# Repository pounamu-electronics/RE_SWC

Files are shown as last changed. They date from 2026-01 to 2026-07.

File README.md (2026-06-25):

# RE_SWC - A volume knob kit for your car

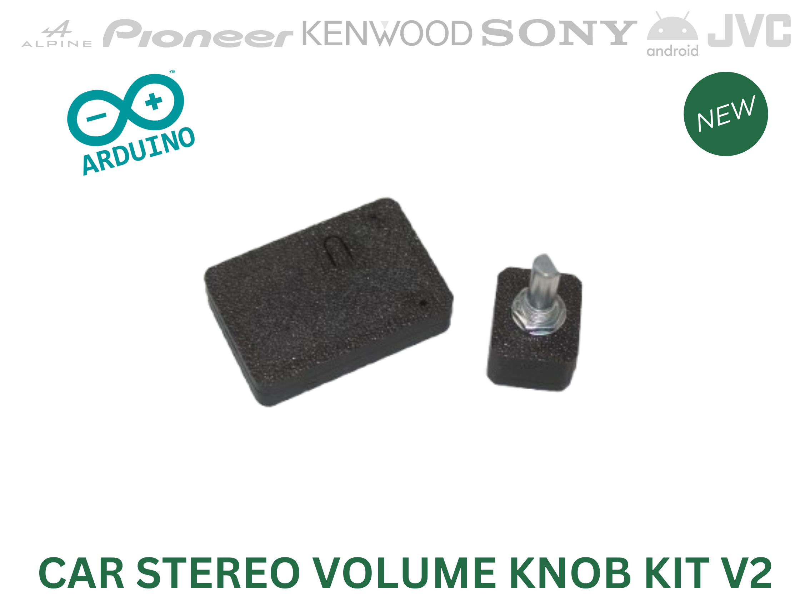
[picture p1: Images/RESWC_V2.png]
RE_SWC Product Render




### Features:

- Simple, **plug-and-play** solution. Mount the volume knob to a panel in the car, solder two wires into your stereo's steering wheel control input and you are good to go
- Compatible with many headunit brands and types
  - Generic Resistive (resistance learning supported by headunits)
  - JVC <sup>1</sup>
  - Kenwood <sup>2</sup>
  - Alpine
  - Pioneer
  - USB HID (single cable control for any android based units)
  - Sony
- **USB C powered**. Most headunits have female USB connectors for you to plug this into and power up
- MCU: WCH CH32X035 programnmed with the Arduino Framework
- Interrupt-driven firmware results in a smooth, **user-freindly** experience
- Firmware via USB upload - easy updates if required
- Fully **open source** hardware and firmware. This includes all design files, BOM, firmware, etc

<sup>1</sup> JVC forces incremental volume control above certain values on select models. I am yet to find a way to bypass this.

<sup>2</sup> Kenwood forces incremental volume control above certain values on select models. I have found a way to bypass this and have implemented it by default in the firmware. This may or may not work for your unit and your miles may vary.

### Default Output Mapping

| INPUT | OUTPUT |
| :---: | :---: |
| Volume Knob Clockwise Rotation (CW) | Volume+ |
| Volume Knob Counter Clockwise Rotation (CCW) | Volume- |
| Button Short Press | Mute/ATT |
| Button Long Press | Next Track |
| Button Double Press (Generic Resistive) | Enable Learning Mode |
| Button Double Press (Others) | Previous Track |

### Output Function Support

_FW v_4.0.0_

| OUTPUT | JVC | KENWOOD | ALPINE | PIONEER | USB HID | SONY |
| :---: | :---: | :---: | :---: | :---: | :---: | :---: |
| Volume+ | :heavy_check_mark: | :heavy_check_mark: | :heavy_check_mark: | :heavy_check_mark: | :heavy_check_mark: | :heavy_check_mark: |
| Volume- | :heavy_check_mark: | :heavy_check_mark: | :heavy_check_mark: | :heavy_check_mark: | :heavy_check_mark: | :heavy_check_mark: |
| Mute/ATT | :heavy_check_mark: | :heavy_check_mark: | :heavy_check_mark: | :heavy_check_mark: | :heavy_check_mark: | :heavy_check_mark: |
| Next Track | :heavy_check_mark: | :heavy_check_mark: | :heavy_check_mark: | :heavy_check_mark: | :heavy_check_mark: | :heavy_check_mark: |
| Previous Track | :heavy_check_mark: | :heavy_check_mark: | :heavy_check_mark: | :heavy_check_mark: | :heavy_check_mark: | :heavy_check_mark: |
| Play/Pause | :x: | :heavy_check_mark: | :x: | :x: | :heavy_check_mark: | :x: |
| Change Source  | :x: | :x: | :x: | :heavy_check_mark: | :x: | :x: |

### User Config

Remap all the input for the Volume Knob Kit to any supported output using the [Configurator Tool](https://pounamu-electronics.github.io/)

### User Guide

The User Guide can be found in the [Docs](Docs/) subfolder of this repository

### Firmware

The FW for this project is also completely open source and hosted [here on GitHub](https://github.com/lilindian16/RE_SWC_FW)

### Why did I make this?

- No kits like this exist: a plug-and-play solution to add a volume knob back into your car. Mount the volume knob to a panel in the car, solder two wires and you are good to go

### My headunit does not have a USB socket to power this??

No worries, purchase an automotive 12V to USB adapter and plug this into it.

- _Note: The 12V rail in cars is harsh. Do not cheap out on this component_

### FCC Compliance Statement

This device complies with Part 15 of the FCC Rules. Operation is subject to the following two conditions:

1.  This device may not cause harmful interference, and
2.  this device must accept any interference received, including interference that may cause undesired operation.

Please note, if you manufacture this yourself, FCC compliance is not valid. Pounamu Electronics is the sole manufacturer listed on the FCC SDoC.

### RESWC Impact Map

[RESWC Impact Map](https://www.google.com/maps/d/edit?mid=1JDZoqSFC2vp5jECxEuNOUrSM_snK-p8&usp=sharing)

### 3D Printed Housings - Design Files

You can find all design and production files for all housings (controller and encoder PCB) in this repo or head to thingiverse and download: [Thingiverse - RE_SWC Housings](https://www.thingiverse.com/thing:7272091)

### Volume Knob Dimensions

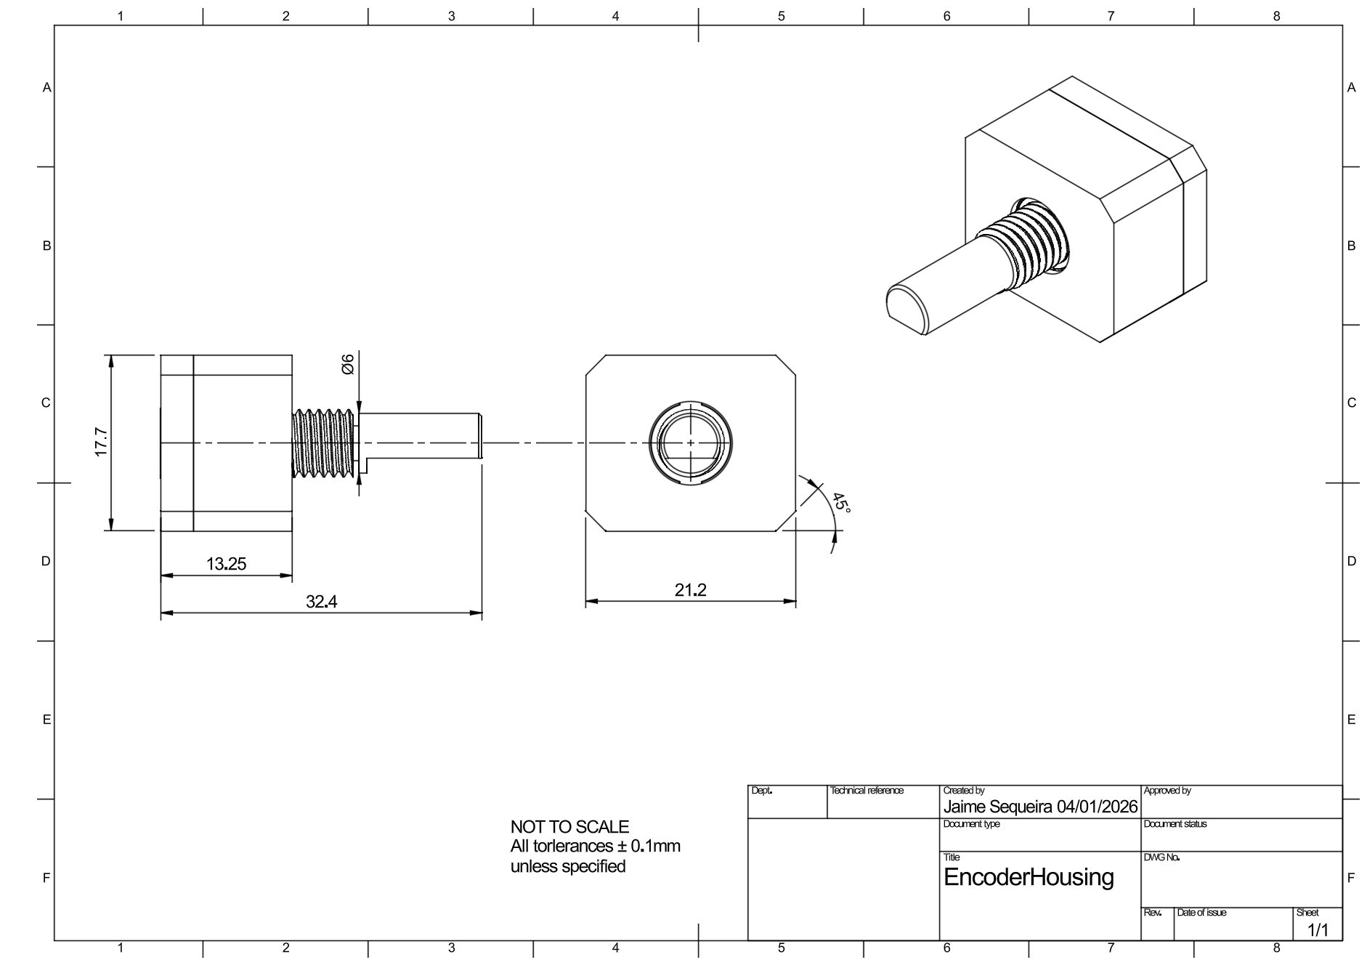
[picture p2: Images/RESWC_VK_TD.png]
Volume Knob Dimensions


### Controller Housing Dimensions

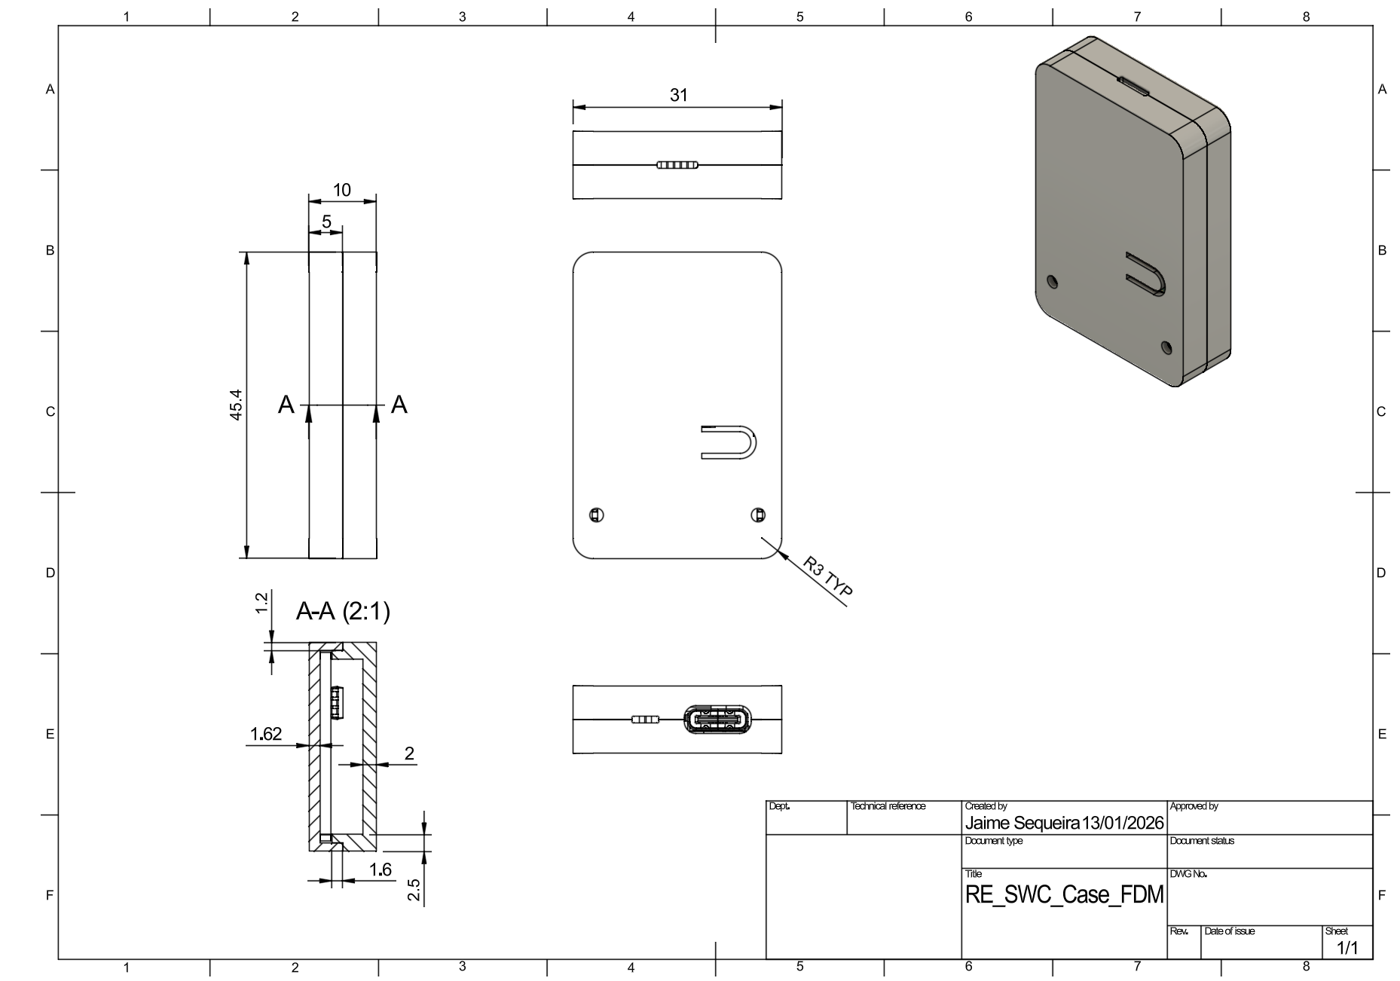
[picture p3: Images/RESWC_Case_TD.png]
Controller Housing Dimensions


### Board Bringup and O'Scope Captures

#### 3V3 Regulator

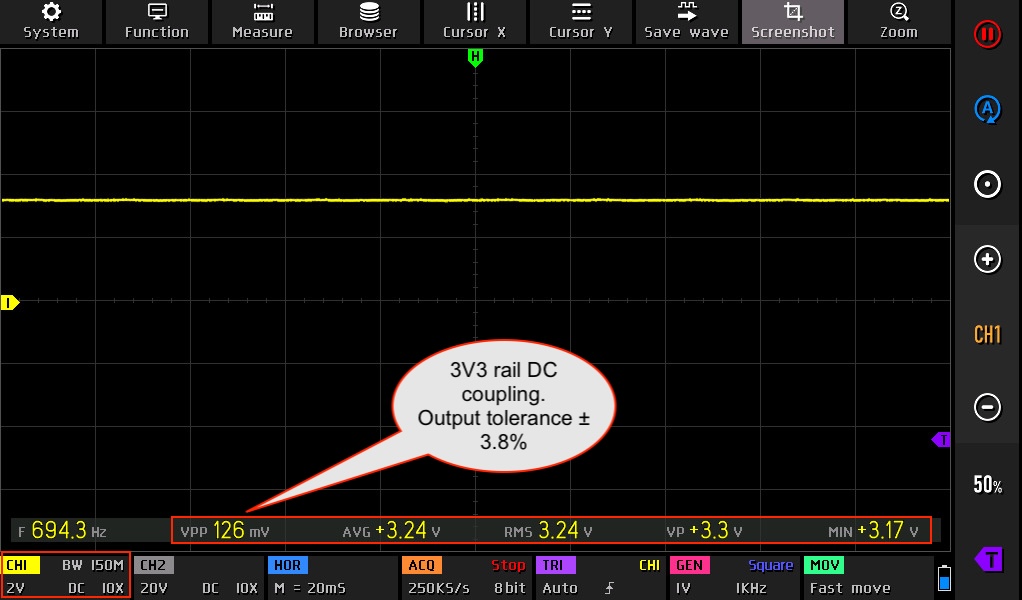
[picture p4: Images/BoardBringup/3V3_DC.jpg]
3V3 Regulator (HT7533-1) DC Coupling

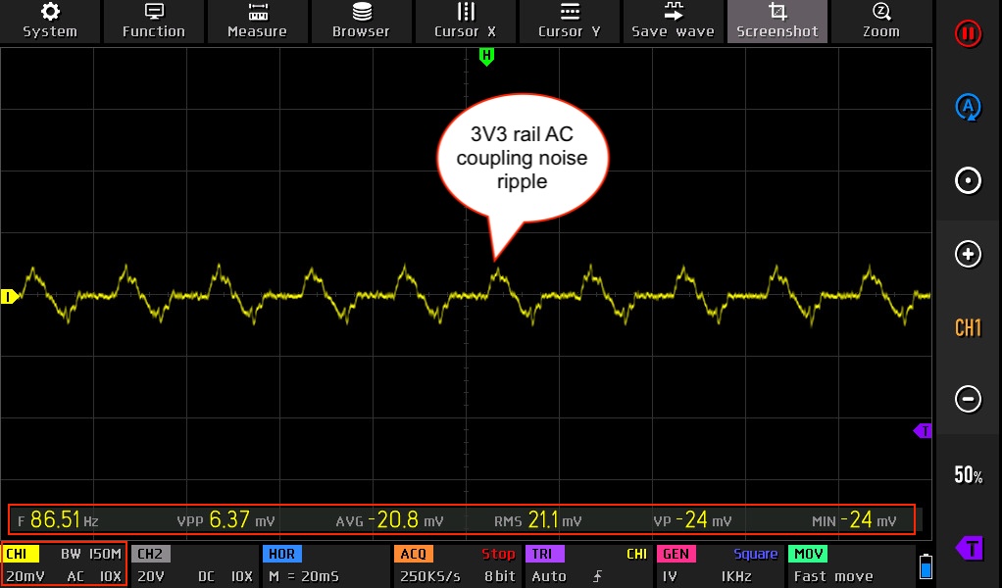
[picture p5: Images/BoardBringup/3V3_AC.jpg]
3V3 Regulator (HT7533-1) AC Coupling


#### Encoder CW, CCW Rotation and Button Press

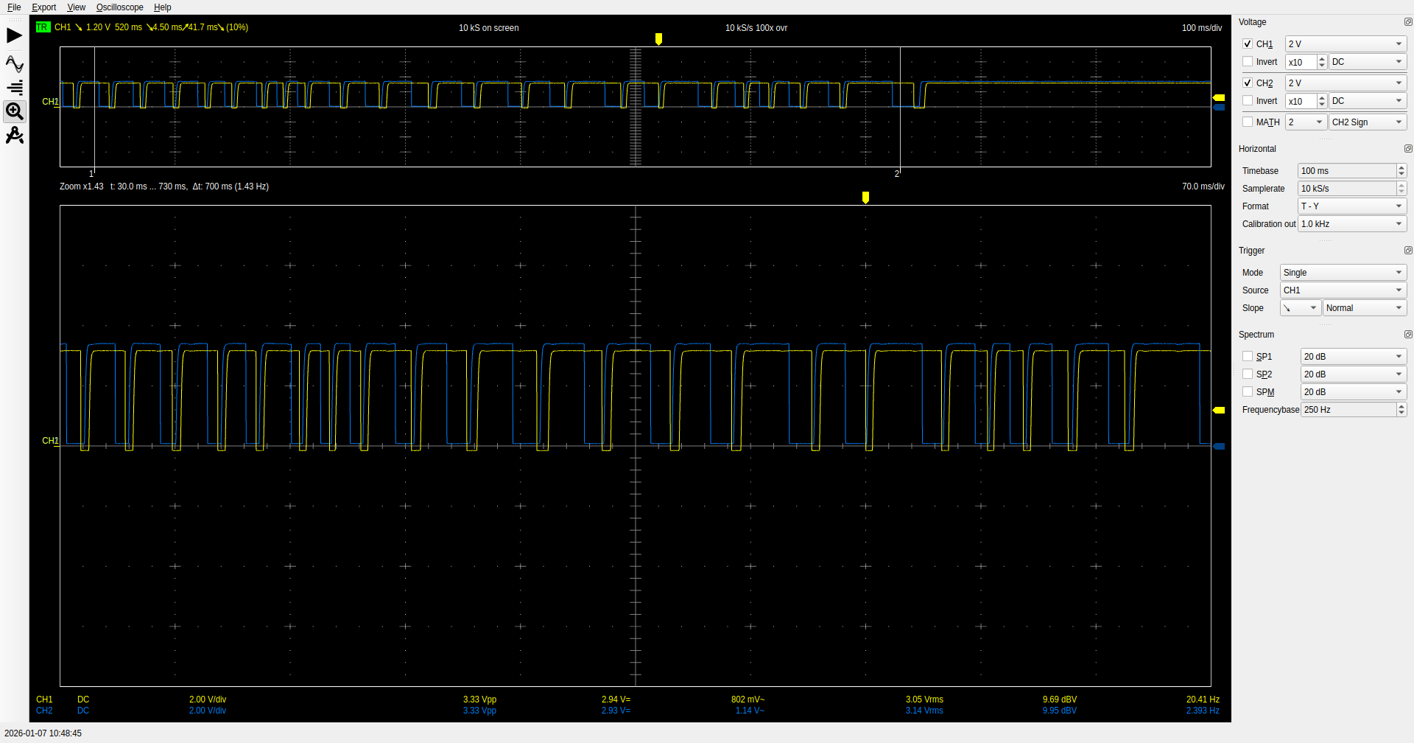
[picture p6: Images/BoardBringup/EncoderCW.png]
Encoder CW

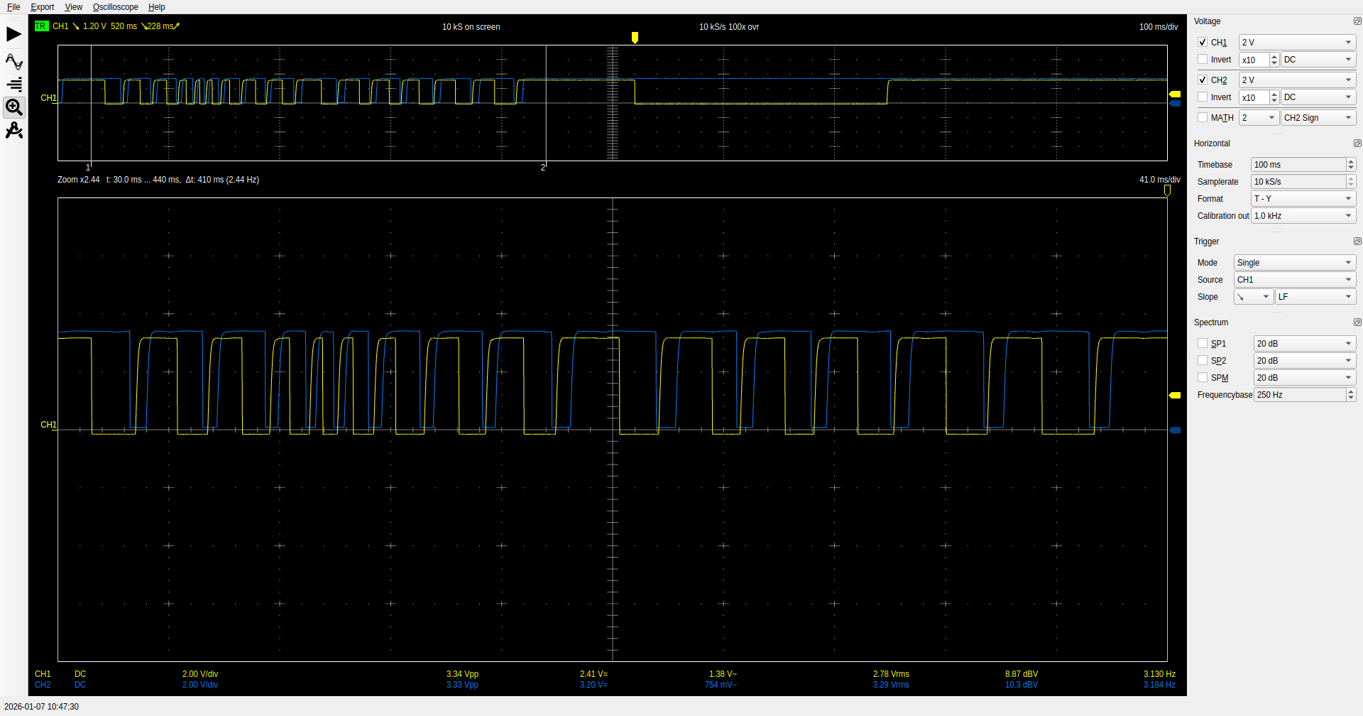
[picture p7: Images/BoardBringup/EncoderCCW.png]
Encoder CCW

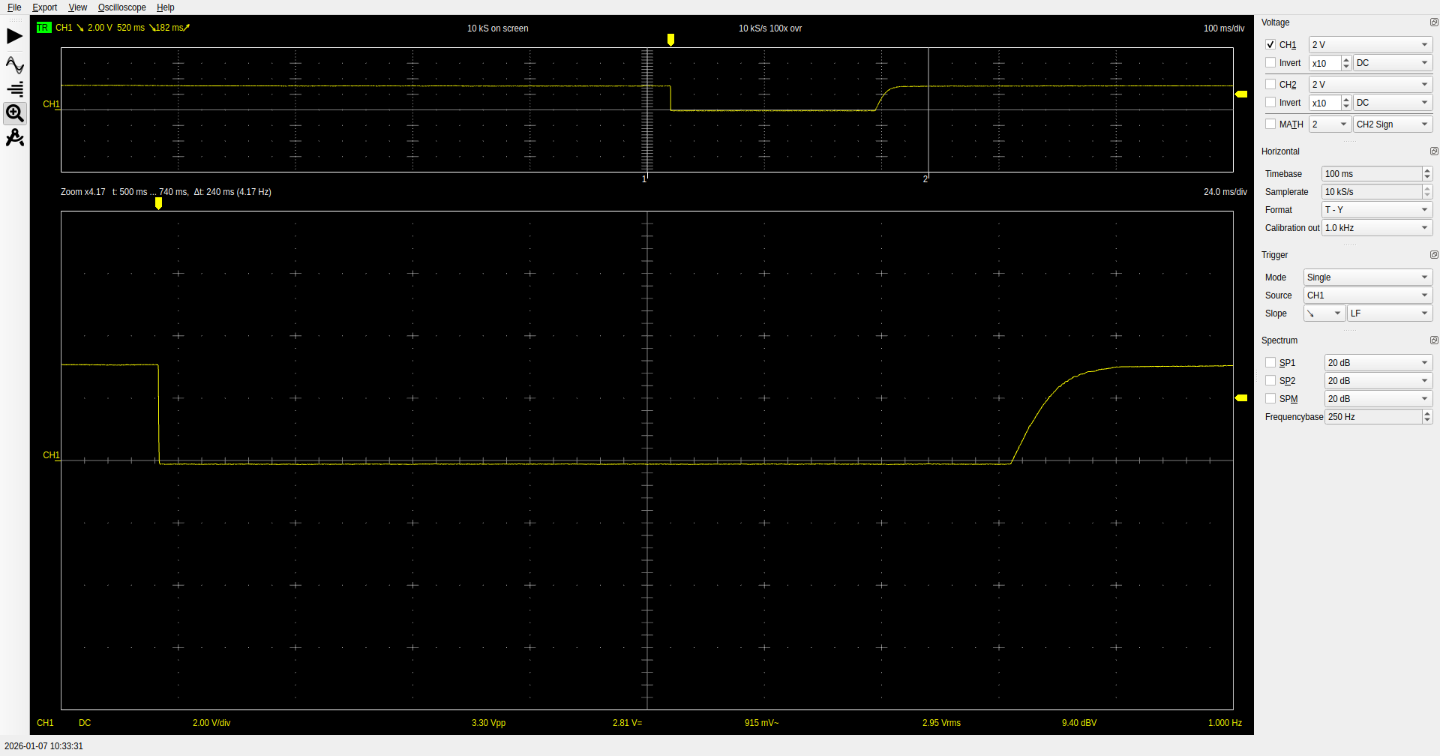
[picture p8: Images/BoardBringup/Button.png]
Encoder Button


#### SPI Bus (Mode 0)

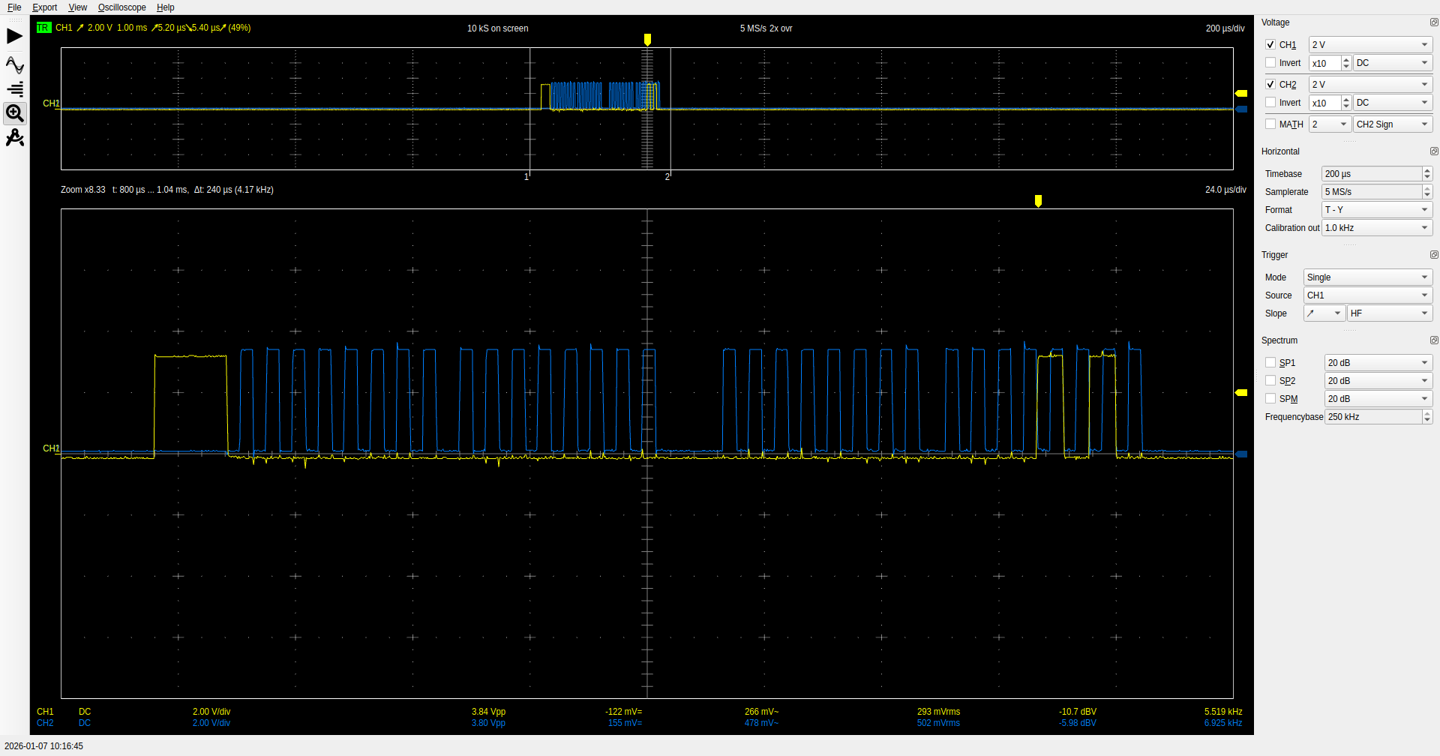
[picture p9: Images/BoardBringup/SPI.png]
SPI


#### Apline SWC Output

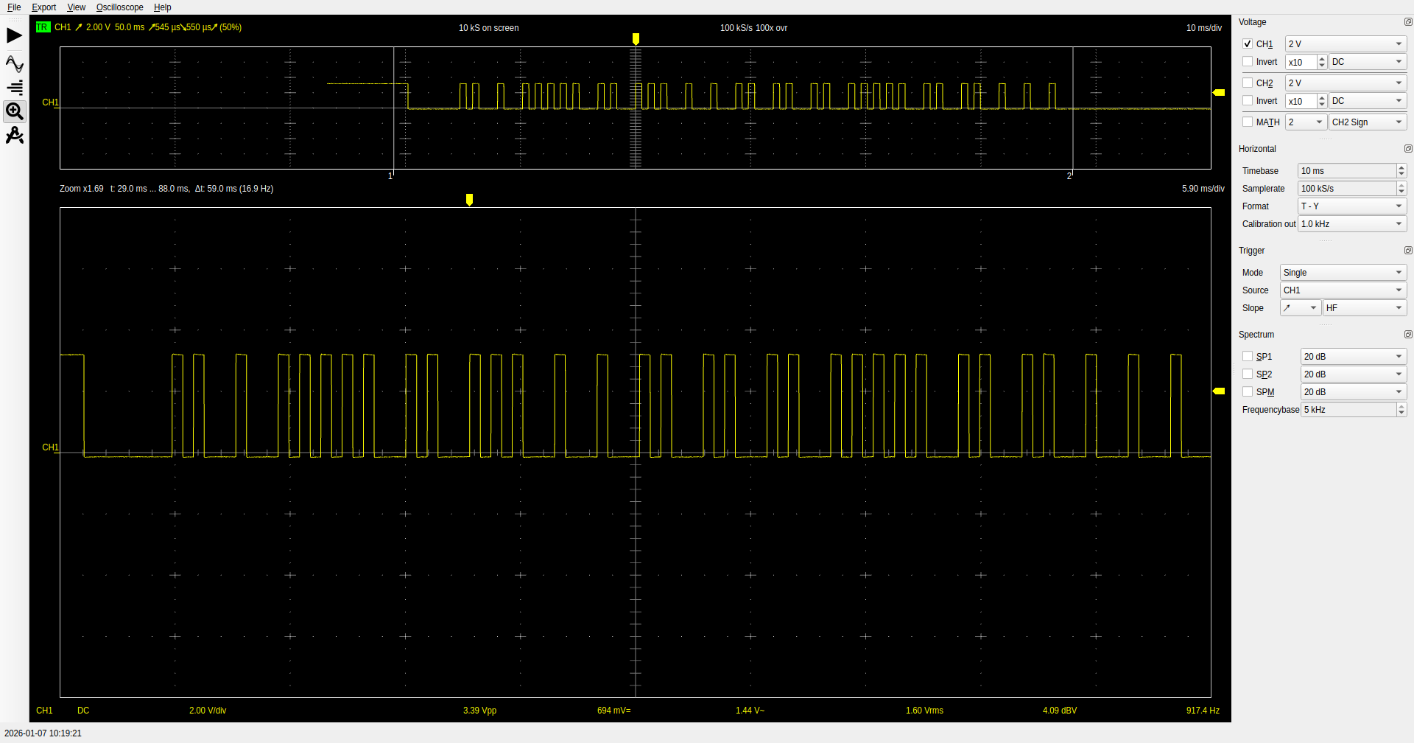
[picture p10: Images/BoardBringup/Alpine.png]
Alpine SWC Output


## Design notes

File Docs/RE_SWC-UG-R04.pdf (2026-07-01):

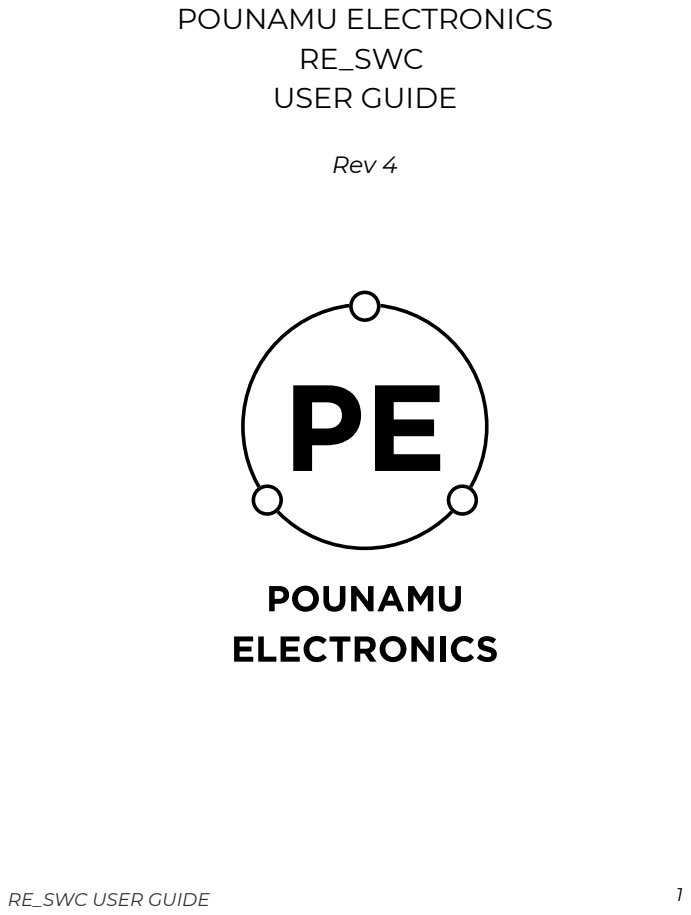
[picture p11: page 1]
RE_SWC USER GUIDE; POUNAMU ELECTRONICS RE_SWC USER GUIDE; Rev 4

3 | OVERVIEW
4 | INSTALLATION GUIDES
| 4 INSTALLATION - GENERIC RESISTIVE
| 5 INSTALLATION - JVC
| 6 INSTALLATION - KENWOOD
| 7 INSTALLATION - ALPINE
| 8 INSTALLATION - PIONEER
| 9 INSTALLATION - USB HID
| 10 INSTALLATION - SONY
11 | CONFIGURATION - HEADUNIT SELECTION
12 | HEADUNIT LEGEND
13 | DEFAULT FUNCTIONS
14 | ASSEMBLY TIPS
15 | VOLUME KNOB DIMESIONS
16 | TROUBLESHOOTING
17 | RE_SWC SPECS
18 | DISCLAIMERS
19 | COMPLIANCE
20 | DOCUMENT REVISION HISTORY

2

### Contents

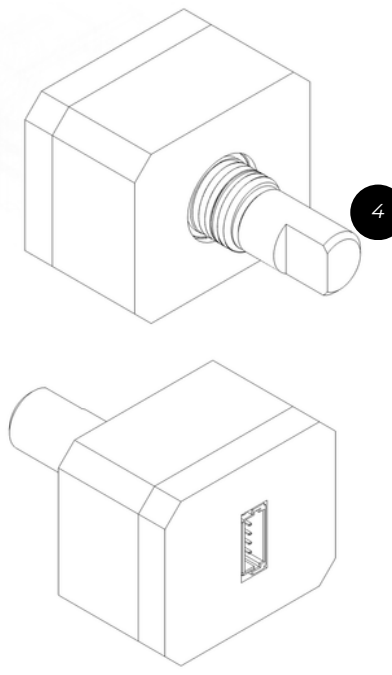
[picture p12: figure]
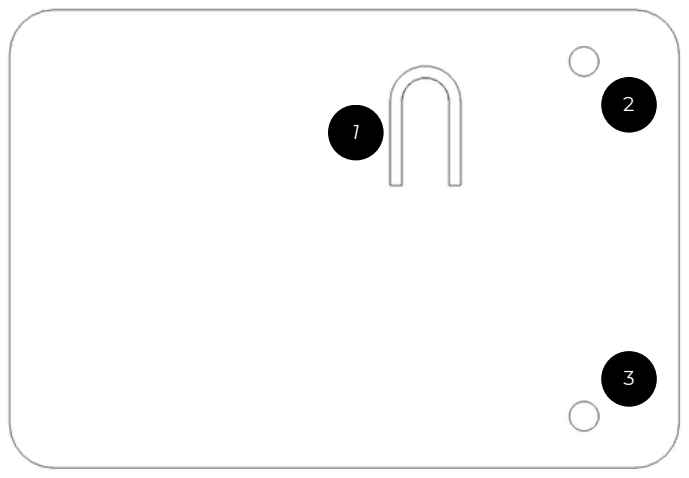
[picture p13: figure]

1. UPDATE BUTTON | 2. WHITE STATUS LIGHT
3. RED POWER LIGHT | 4. DIA 6mm ENCODER SHAFT
RE_SWC USER GUIDE | 3

### OVERVIEW

4

### INSTALLATION - GENERIC RESISTIVE

Solder the RED wire from the 2-pin connector on the RE_SWC kit to your headunit’s steering wheel control input pin (generally labelled KEY1 or KEY2)
If you purchased the 3.5mm patch cable, this will be the tip of the TRS jack
Solder the BLACK wire from the 2-pin connector into your harness if your headunit requires a reference for the SWC input (sometimes labelled ST REMOTE GND)
If you purchased the 3.5mm patch cable, this will be the sleeve of the TRS jack
Power the kit with a USB C cable.
NOTE: This kit requires 5V USB power only The RED power indicator on the RE_SWC will illuminate and stay on

5

### INSTALLATION - JVC

Solder the RED wire from the 2-pin connector on the RE_SWC kit to your headunit’s steering wheel control input pin (normally a blue and yellow wire)
If you purchased the 3.5mm patch cable, this will be the tip of the TRS jack
Power the kit with a USB C cable.
NOTE: This kit requires 5V USB power only The RED power indicator on the RE_SWC will illuminate and stay on
The RE_SWC kit will operate without any further configuration on your headunit

6

### INSTALLATION - KENWOOD

Solder the RED wire from the 2-pin connector on the RE_SWC kit to your headunit’s steering wheel control input pin (normally a blue and yellow wire)
If you purchased the 3.5mm patch cable, this will be the tip of the TRS jack
Power the kit with a USB C cable.
NOTE: This kit requires 5V USB power only The RED power indicator on the RE_SWC will illuminate and stay on
The RE_SWC kit will operate without any further configuration on your headunit

7

### INSTALLATION - ALPINE

Plug the RE_SWC into your unit using the 3.5mm patch cable
You can make a compatible 3.5mm patch cable yourself by soldering the red wire from the 2-pin connector on the RE_SWC kit to the tip of the 3.5mm jack. Leave the ring and sleeve floating
Power the kit with a USB C cable.
NOTE: This kit requires 5V USB power only The RED power indicator on the RE_SWC will illuminate and stay on
The RE_SWC kit will operate without any further configuration on your headunit

8

### INSTALLATION - PIONEER

Plug the RE_SWC into your unit using the 3.5mm patch cable
You can make a compatible 3.5mm patch cable yourself by soldering the red wire from the 2-pin connector on the RE_SWC kit to the tip of the 3.5mm jack. Leave the ring and sleeve floating
Power the kit with a USB C cable.
NOTE: This kit requires 5V USB power only The RED power indicator on the RE_SWC will illuminate and stay on
Ensure “With Adapter” is set in the Steering Wheel Controls menu on your headunit
The RE_SWC kit will operate without any further configuration on your headunit

9

### INSTALLATION - USB HID

Connect the RE_SWC kit to your device with a USB C cable (must support data & 5V power) Note: Do not use this device with any power source higher than standard USB 5V
The RED power indicator on the RE_SWC will illuminate and stay on

10

### INSTALLATION - SONY

Plug the RE_SWC into your unit using the 3.5mm patch cable
You can make a compatible 3.5mm patch cable yourself by soldering the red wire from the RE_SWC kit to the tip of the 3.5mm jack. Leave the ring and sleeve floating
Power the kit with a USB C cable.
NOTE: This kit requires 5V USB power only The RED power indicator on the RE_SWC will illuminate and stay on
In the Steering Wheel Controls menu, set the [Custom] switch to [OFF]
On some units, you may need to set it to be “With Adapter”
The RE_SWC kit will operate without any further configuration on your headunit

11

### CONFIGURATION - HEADUNIT SELECTION

Ensure RE_SWC is not powered
Press and hold the volume knob. Connect power to the RE_SWC while keeping the volume knob held
Release the volume knob after the WHITE status light is illuminated
Press the volume knob once. The WHITE status light will flash once. Headunit number 1 is now programmed. Repeat this step until the desired headunit number is reached - refer to the headunit legend
When the desired headunit number is entered, press and hold the volume knob. The WHITE status light will flash. Release the volume knob. The RE_SWC will flash x times where x is the headunit number entered

12

### HEADUNIT LEGEND

HEADUNIT NUMBER | HEADUNIT TYPE / BRAND

1 GENERIC RESISTIVE

2 JVC

3 KENWOOD

4 ALPINE

5 PIONEER

6 USB HID

7 SONY

13

### DEFAULT FUNCTIONS

INPUT | OUTPUT
Volume Knob CW | Volume +
Volume Knob CCW | Volume -
Button Short Press | Mute
Button Long Press | Next Track
Button Double Press (Generic Resistive mode) | Enable Learning Mode
Button Double Press (Other Modes) | Previous Track

RE_SWC USER GUIDE | 14

### ASSEMBLY TIPS

Mounting the knob
Drill a pilot hole between 1 and 3mm in diameter Widen the hole to 7.5mm
Mount the knob into the hole and secure with the included washer and nut

Powering the RE

_

SWC
The RE_SWC uses 5V USB power. Do not use any higher voltage
The RE_SWC boots up almost instantaneously. You can power the device with a switched 5V USB power supply. Configuration settings are retained between power cycles

Note
The RE_SWC will be shipped pre-configured in the mode selected during the checkout process for a plug-and-play setup

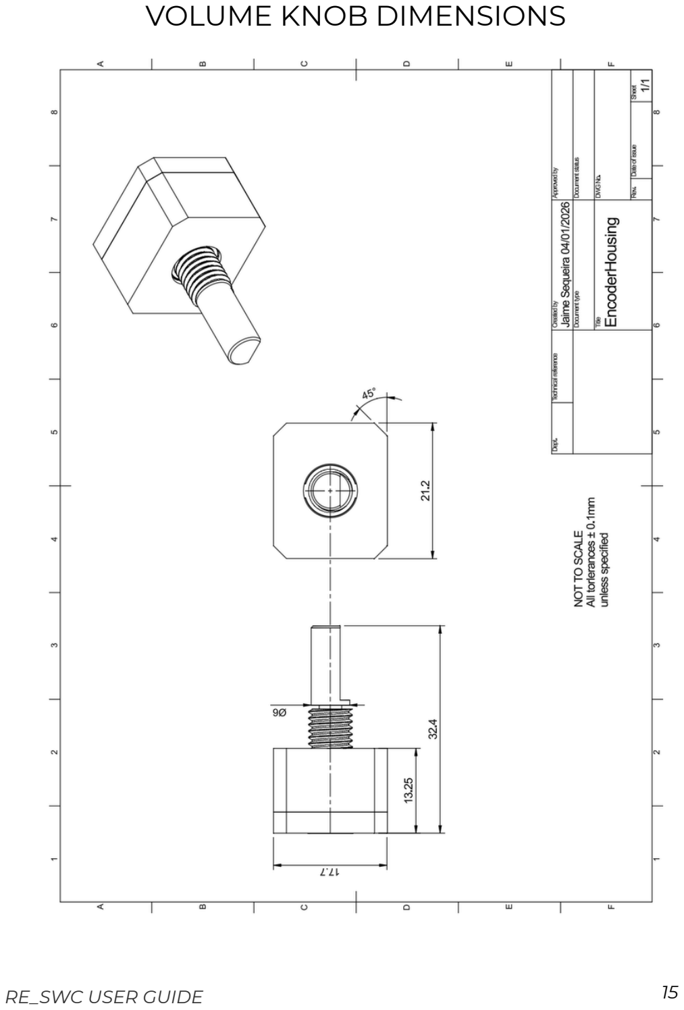
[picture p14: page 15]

RE_SWC USER GUIDE | 15

### VOLUME KNOB DIMENSIONS

16

### TROUBLESHOOTING

The RED power light is off
Ensure you are powering the kit with 5V USB power

The RED power light is on but the WHITE status light does not flash when I use the knob Ensure the 5-pin connector harness for the knob is seated correctly and inserted fully into the knob and the kit

The WHITE status light flashes when I turn the knob but my headunit does nothing
Ensure you have set the kit in the correct headunit mode
Ensure the RED wire from the 2-pin connector is soldered properly into your headunit’s harness

My headunit shows the volume increasing but the volume of my music doesn’t change in USB HID mode
Some Android headunits do not route USB volume commands to the correct hardware. Revert to using the Resistive SWC mode with Key1 / Key 2 input wire instead

### RE_SWC SPECS

Input
Power: 5V / 100mA USB-C
SWC Header: 5V max. Do not connect to 12V signal

CONNECTORS
VOLUME KNOB: JST SHR-05V-S-B SWC OUT: JST SHR-02V-S-B

MCU:
WCH CH32X035F8U6

Digital Rheostat:
MCP4131-104E/SN
SPI @ 250kHz
RE_SWC USER GUIDE | 17

18

### DISCLAIMERS

Pounamu Electronics is not affiliated or associated with any headunit manufacturers or brands
Pounamu Electronics is not affiliated or associated with the USB Implementers Forum (USB-IF)

19

### COMPLIANCE

FCC Compliance Statement
This device complies with Part 15 of the FCC Rules. Operation is subject to the following two
conditions:
1. This device may not cause harmful interference, and
2. this device must accept any interference received, including interference that may cause undesired operation.

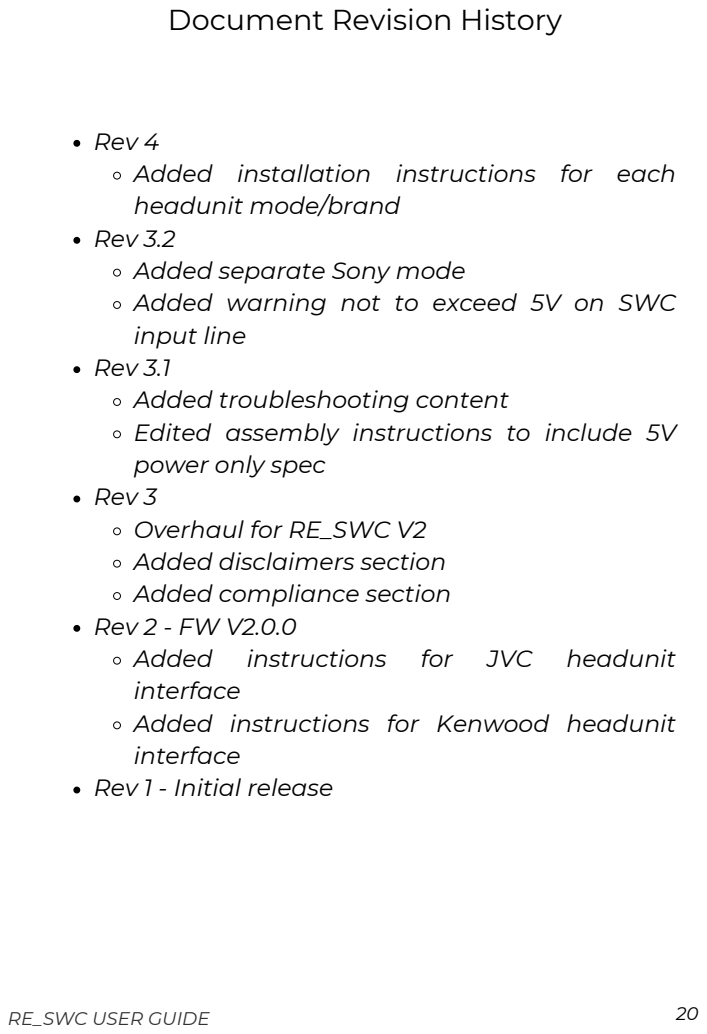
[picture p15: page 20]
RE_SWC USER GUIDE

Document Revision History

Rev 4
Added installation instructions for each
headunit mode/brand
Rev 3.2
Added separate Sony mode
Added warning not to exceed 5V on SWC
input line
Rev 3.1
Added troubleshooting content
Edited assembly instructions to include 5V
power only spec
Rev 3
Overhaul for RE_SWC V2
Added disclaimers section
Added compliance section
Rev 2 - FW V2.0.0
Added instructions for JVC headunit
interface
Added instructions for Kenwood headunit
Rev 1 - Initial release

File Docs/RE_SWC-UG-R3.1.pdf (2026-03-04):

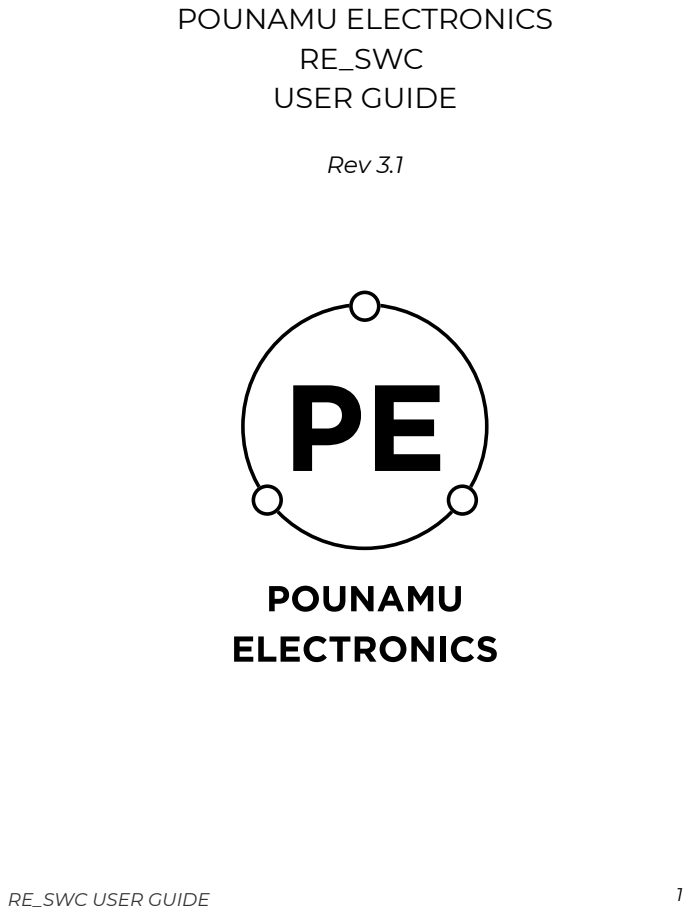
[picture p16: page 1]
RE_SWC USER GUIDE; POUNAMU ELECTRONICS RE_SWC USER GUIDE; Rev 3.1

3 | OVERVIEW
4 | ASSEMBLY
5 | CONFIGURATION - HEADUNIT SELECTION
6 | HEADUNIT LEGEND
7 | FUNCTIONS
8 | VOLUME KNOB DIMESIONS
9 | TROUBLESHOOTING
10 | RE_SWC SPECS
11 | DISCLAIMERS
12 | COMPLIANCE
13 | DOCUMENT REVISION HISTORY

2

### Contents


1. UPDATE BUTTON | 2. WHITE STATUS LIGHT
3. RED POWER LIGHT | 4. DIA 6mm ENCODER SHAFT
RE_SWC USER GUIDE | 3

### OVERVIEW

RE_SWC USER GUIDE | 4

### ASSEMBLY

Solder the RED wire from the 2-pin connector on the RE_SWC kit to your headunit’s steering wheel control input pin
Solder the BLACK wire from the 2-pin connector into your harness if your headunit requires a reference for the SWC input (sometimes labelled ST REMOTE GND)
Power the kit with a USB C cable.
NOTE: This kit requires 5V USB power only The RED power indicator on the RE_SWC will imlluminate and stay on

USB HID
Connect the RE_SWC kit to your device with a USB C cable (must support data & 5V power) The RED power indicator on the RE_SWC will imlluminate and stay on

Others

5

### CONFIGURATION

HEADUNIT SELECTION

Ensure RE_SWC is not powered
Press and hold the volume knob. Connect power to the RE_SWC while keeping the volume knob held
Release the volume knob after the WHITE status light is illuminated
Press the volume knob once. The WHITE status light will flash once. Headunit number 1 is now programmed. Repeat this step until the desired headunit number is reached - refer to the headunit legend
When the desired headunit number is entered, press and hold the volume knob. The WHITE status light will flash. Release the volume knob. The RE_SWC will flash x times where x is the headunit number entered

6

### HEADUNIT LEGEND

HEADUNIT NUMBER | HEADUNIT TYPE / BRAND

1 GENERIC RESISTIVE

2 JVC

3 KENWOOD

4 ALPINE

5 PIONEER / SONY

6 USB HID

7

### FUNCTIONS

INPUT | GENERIC RESISTIVE | JVC | KENWOOD | ALPINE | PIONEER / SONY | USB HID
Volume Knob CW | Any | Volume + | Volume + | Volume + | Volume + | Volume +
Volume Knob CCW | Any | Volume - | Volume - | Volume - | Volume - | Volume -
Button Short Press | Any | Mute | Mute | Mute | Mute | Mute
Button Long Press | Any | Next Track | Next Track | Next Track | Next Track | Next Track
Button Double Press | Enter Learning Mode | Previous Track | Previous Track | Previous Track | Previous Track | Previous Track

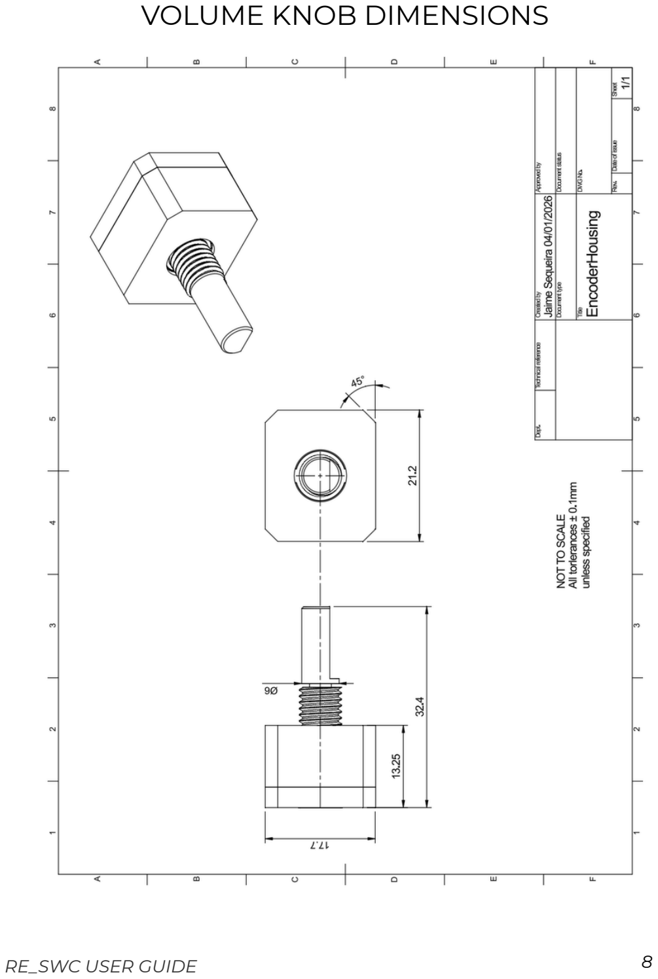
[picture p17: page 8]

RE_SWC USER GUIDE | 8

### VOLUME KNOB DIMENSIONS

9

### TROUBLESHOOTING

The RED power light is off
Ensure you are powering the kit with 5V USB power

The RED power light is on but the WHITE status light does not flash when I use the knob Ensure the 5-pin connector harness for the knob is seated correctly and inserted fully into the knob and the kit

The WHITE status light flashes when I turn the knob but my headunit does nothing
Ensure you have set the kit in the correct headunit mode
Ensure the RED wire from the 2-pin connector is soldered properly into your headunit’s harness

My headunit shows the volume increasing but the volume of my music doesn’t change in USB HID mode
Some Android headunits do not route USB volume commands to the correct hardware. Revert to using the Resistive SWC mode with Key1 / Key 2 input wire instead

### RE_SWC SPECS

Input
5V / 100mA USB-C

CONNECTORS
VOLUME KNOB: JST SHR-05V-S-B SWC OUT: JST SHR-02V-S-B

MCU:
WCH CH32X035F8U6

Digital Rheostat:
MCP4131-104E/SN
SPI @ 250kHz
RE_SWC USER GUIDE | 10

11

### DISCLAIMERS

Pounamu Electronics is not affiliated or associated with any headunit manufacturers or brands
Pounamu Electronics is not affiliated or associated with the USB Implementers Forum (USB-IF)

12

### COMPLIANCE

FCC Compliance Statement
This device complies with Part 15 of the FCC Rules. Operation is subject to the following two
conditions:
1. This device may not cause harmful interference, and
2. this device must accept any interference received, including interference that may cause undesired operation.

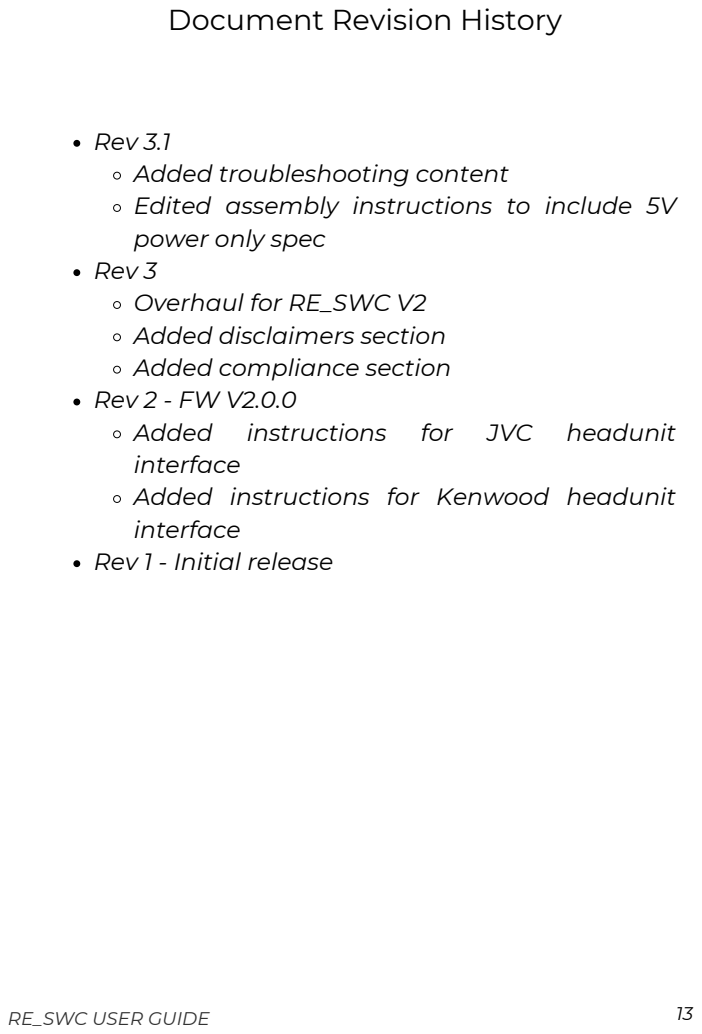
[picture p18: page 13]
RE_SWC USER GUIDE

Document Revision History

Rev 3.1
Added troubleshooting content
Edited assembly instructions to include 5V
power only spec
Rev 3
Overhaul for RE_SWC V2
Added disclaimers section
Added compliance section
Rev 2 - FW V2.0.0
Added instructions for JVC headunit
interface
Added instructions for Kenwood headunit
Rev 1 - Initial release

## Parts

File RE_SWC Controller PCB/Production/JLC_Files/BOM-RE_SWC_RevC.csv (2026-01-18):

Comment | Designator | Footprint | LCSC | Quantity
SM05B-SRSS-TB | J104 | JST_SH_SM05B-SRSS-TB_1x05-1MP_P1.00mm_Horizontal | C136657 | 1
HT7533-1 | U102 | SOT-89-3 | C14289 | 1
100n | C101,C102,C107,C109,C111 | C_0603_1608Metric | C14663 | 5
SM02B-SRSS-TB | J106 | JST_SH_SM02B-SRSS-TB_1x02-1MP_P1.00mm_Horizontal | C160402 | 1
1N5819WS | D109 | D_SOD-323_HandSoldering | C191023 | 1
H3V3SD3B | D102,D105,D106 | D_SOD-323_HandSoldering | C20615802 | 3
H5VSD3B | D107 | D_SOD-323_HandSoldering | C20615806 | 1
AO3400A | Q104 | SOT-23 | C20917 | 1
LED_RED | D103 | LED_0603_1608Metric_Pad1.05x0.95mm_HandSolder | C2286 | 1
LED_WHITE | D104 | LED_0603_1608Metric_Pad1.05x0.95mm_HandSolder | C2290 | 1
330R | R101,R103,R104,R105,R112,R118,R126,R129 | R_0603_1608Metric | C23138 | 8
4R7 | R123 | R_0603_1608Metric | C23164 | 1
5k1 | R119,R120,R127,R128 | R_0603_1608Metric | C23186 | 4
BOOT | SW101 | SW_SPST_B3U-1000P-B | C256107 | 1
GT-USB-7010ASV | J101 | USB_C_Receptacle_G-Switch_GT-USB-7010ASV | C2988369 | 1
CH32X035F8U6 | U107 | QFN-20-1EP_3x3mm_P0.4mm_EP1.65x1.65mm | C42442062 | 1
10n | C105,C106 | C_0603_1608Metric | C57112 | 2
MCP4131-104E/SN | U105 | SOIC-8_3.9x4.9mm_P1.27mm | C636034 | 1
USBLC6-2SC6 | U106 | SOT-23-6 | C7519 | 1
10u | C103,C104,C112 | C_0603_1608Metric | C96446 | 3

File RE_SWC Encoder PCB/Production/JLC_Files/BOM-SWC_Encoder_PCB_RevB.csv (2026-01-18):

Comment | Designator | Footprint | LCSC | Quantity
Rotary Encoder | SW101 | RotaryEncoder_Bourns_Vertical_PEC12R-3x17F-Sxxxx | C19712528 | 1
BM05B-SRSS-TBT(LF)(SN) | J101 | JST_SH_BM05B-SRSS-TB_1x05-1MP_P1.00mm_Vertical | C265092 | 1

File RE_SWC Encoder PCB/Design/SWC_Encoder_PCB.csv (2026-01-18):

Reference | Qty | DNP | Manufacturer | MPN | LCSC | Value | Footprint | Datasheet
SW101 | 1 |  | CTR | ED11305M-FB18.5A10-E20-160-G219 | C19712528 | Rotary Encoder | Rotary_Encoder:RotaryEncoder_Bourns_Vertical_PEC12R-3x17F-Sxxxx | https://lcsc.com/datasheet/lcsc_datasheet_2410121342_CTR-ED11305M-FB18-5A10-E20-160-G219_C19712528.pdf
J101 | 1 |  | JST | BM05B-SRSS-TBT(LF)(SN) | C265092 | BM05B-SRSS-TBT(LF)(SN) | Connector_JST:JST_SH_BM05B-SRSS-TB_1x05-1MP_P1.00mm_Vertical | https://www.lcsc.com/datasheet/lcsc_datasheet_2004071004_JST-BM05B-SRSS-TBT-LF-SN_C265092.pdf

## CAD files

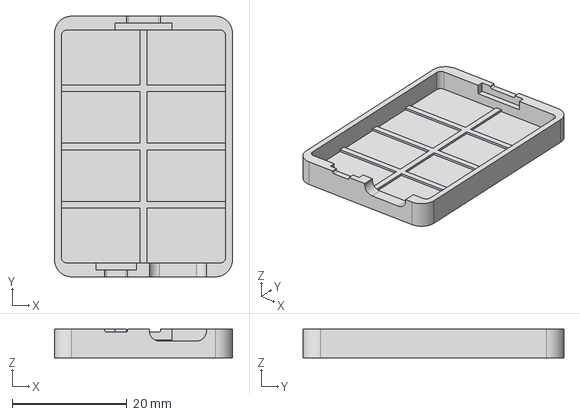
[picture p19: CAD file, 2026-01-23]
RE_SWC Controller Case/FDM/STEP/CaseBase.step
31.0 x 45.4 x 5.00 mm

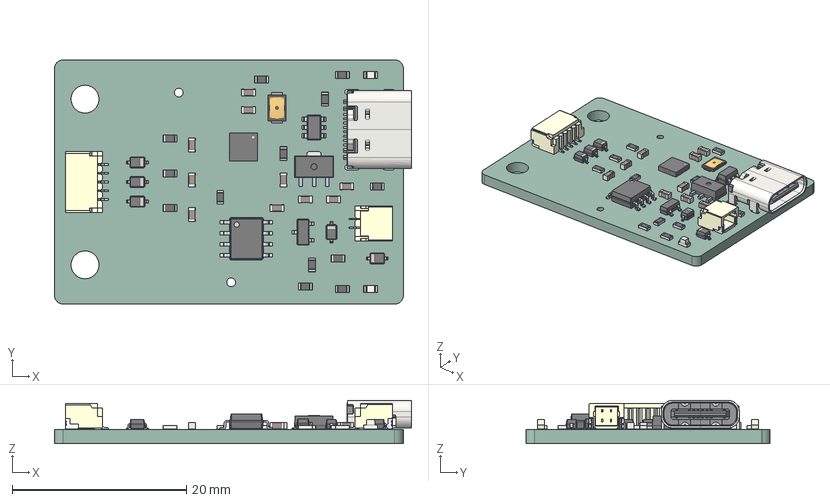
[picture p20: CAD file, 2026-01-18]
RE_SWC Controller PCB/Design/RE_SWC_Controller_PCB.step
40.9 x 28.0 x 4.96 mm
R_0603_1608Metric x 13
C_0603_1608Metric x 10
QFN-20-1EP_4x4mm_Pitch0.5mm
D_SOD_323 x 5
3x2x0.65mm
CQ assembly
SM02B-SRSS-TB(LF)(SN)
SOT_23
SOT_23_6
USB_C_Receptacle_16P_TopMnt_Horizontal_GCT_USB4105-xx-A
LED_0603_1608Metric x 2
SOIC_8_39x49mm_P127mm
SM05B-SRSS-TB-LFS
RE_SWC_RevC_PCB

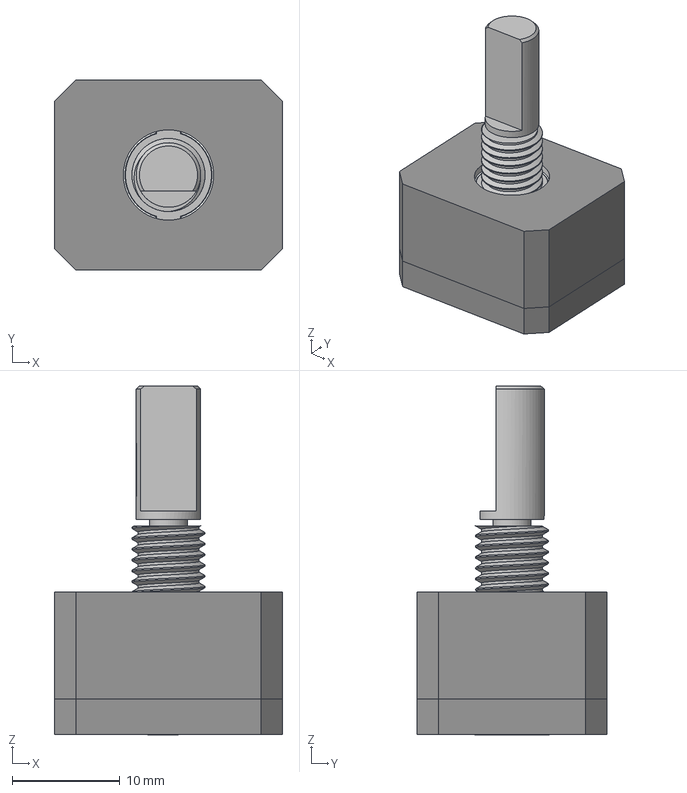
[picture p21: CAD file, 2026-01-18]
RE_SWC Encoder Case/STEP/Encoder_Housing_bottom.step
21.2 x 17.7 x 32.4 mm
EC11_20mm v1
BM05B-SRSS-TB(LF)(SN)
SWC_Encoder_PCB_RevB_PCB

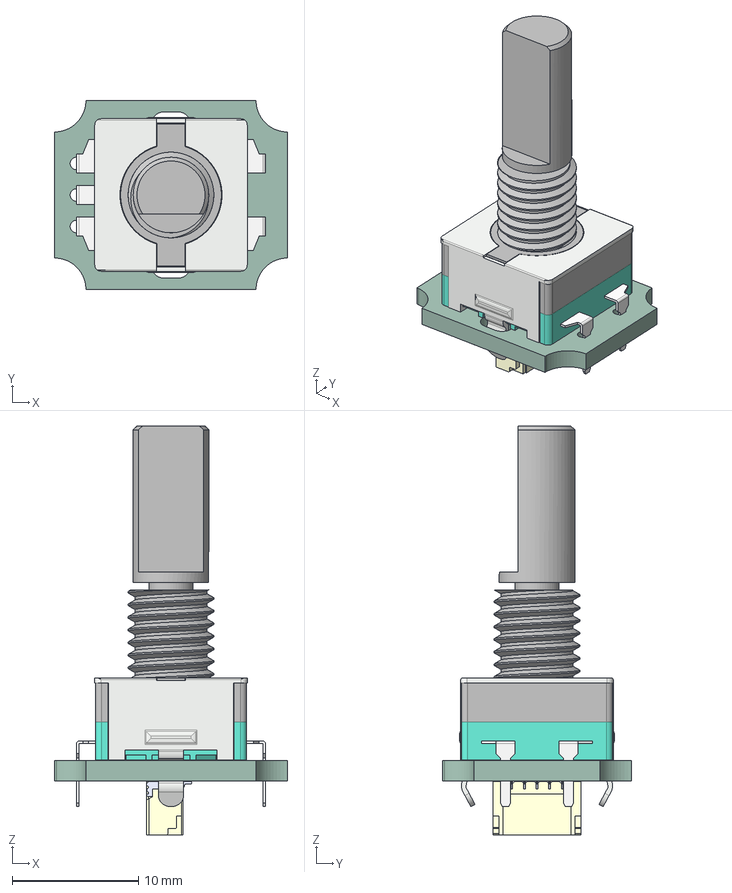
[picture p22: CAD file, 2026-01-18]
RE_SWC Encoder PCB/Design/SWC_Encoder_PCB_RevB.step
18.5 x 15.0 x 32.4 mm
EC11_20mm v1
BM05B-SRSS-TB(LF)(SN)
SWC_Encoder_PCB_RevB_PCB

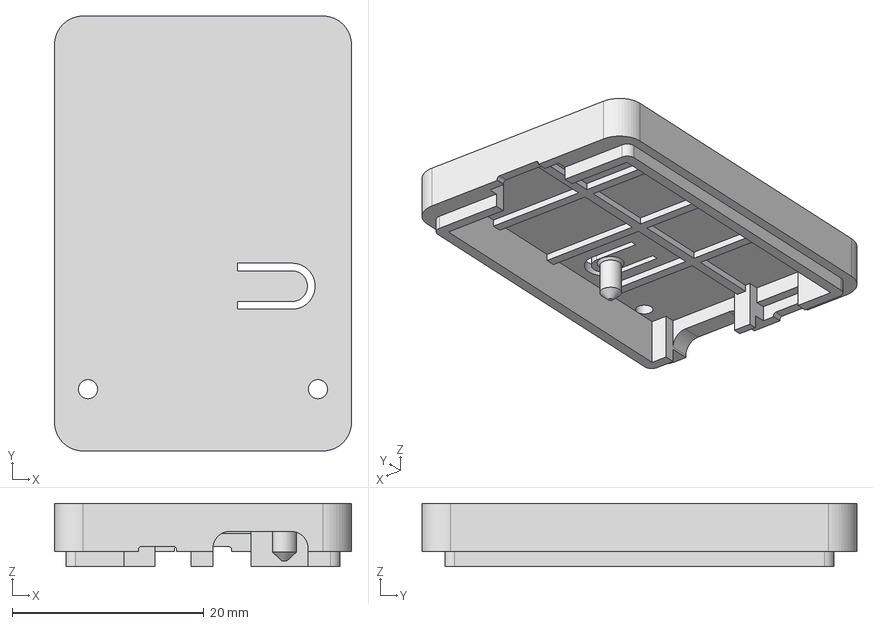
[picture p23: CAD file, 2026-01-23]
RE_SWC Controller Case/FDM/STEP/CaseLid.step
31.0 x 45.4 x 6.60 mm

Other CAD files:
RE_SWC Encoder Case/STEP/Encoder_Housing_top.step
RE_SWC Controller Case/FDM/STL/CaseBase.stl
RE_SWC Controller Case/FDM/STL/CaseLid.stl
RE_SWC Encoder Case/STL/Encoder_Housing_bottom.stl
RE_SWC Encoder Case/STL/Encoder_Housing_top.stl

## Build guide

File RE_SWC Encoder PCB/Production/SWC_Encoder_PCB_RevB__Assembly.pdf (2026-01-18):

No | Not specified | 0.01 | mm

# Min hole diameter: Not specified

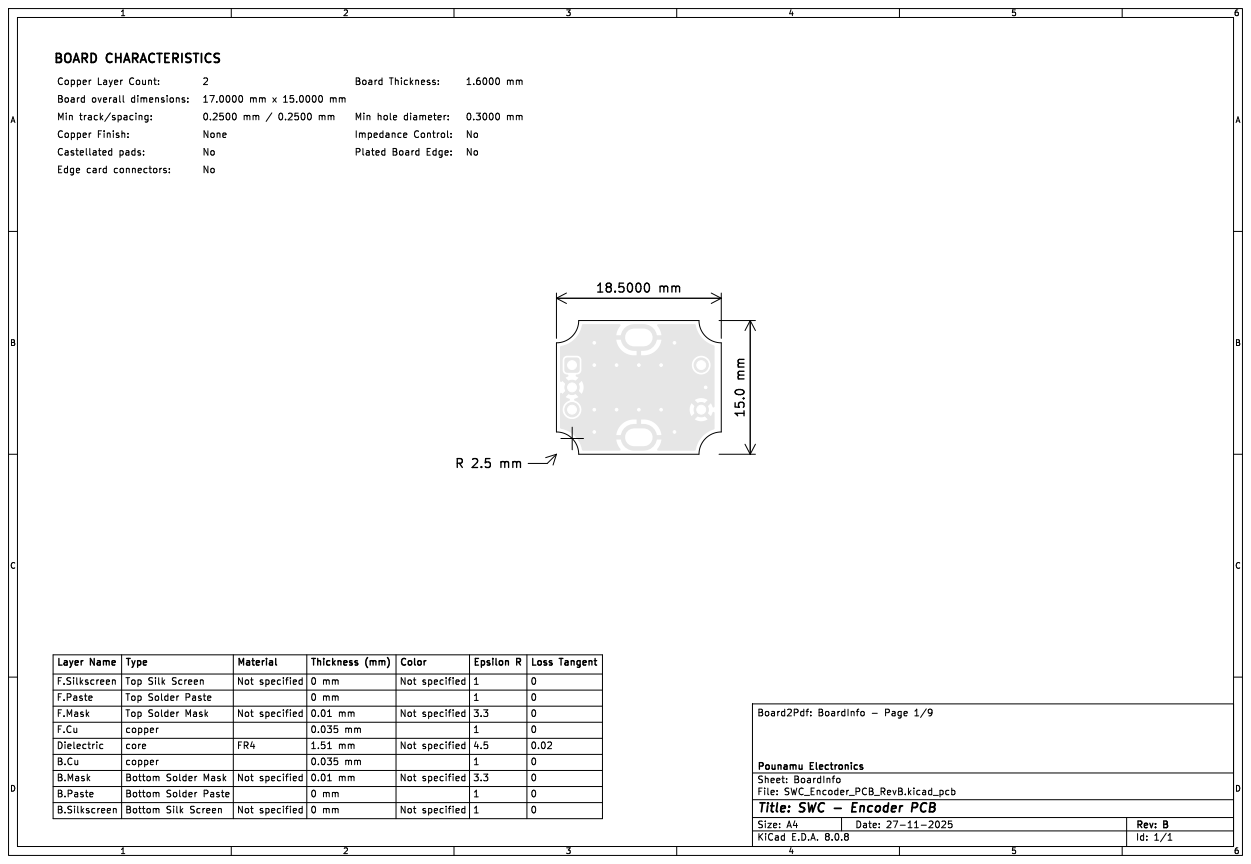
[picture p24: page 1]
D Date: 27-11-2025 KiCad; E.D.A. 8.0.8 Size: A4; Rev:; File: SWC_Encoder_PCB_RevB.kicad_pcb Sheet: BoardInfo Pounamu; Electronics Board2Pdf:; BoardInfo; Page; Board; Thickness:; Impedance; Control:; B.Paste; Edge card; connectors:; Not specified; B.Mask; Epsilon; Board overall; dimensions:; Castellated; pads:; BOARD CHARACTERISTICS; Copper Finish:; None

Copper Layer Count:
Min track/spacing:

Plated Board Edge:

Top Solder Paste | | 0 mm | | | 0 F.Mask Dielectric Layer Name F.Paste F.Cu

Bottom Solder Mask F.Silkscreen | | Screen Top Solder | Screen Mask | | Not specified | | Thickness | (mm) | Color Bottom Silk Not specified B.Silkscreen Not specified | 1 Not specified B.Cu 3.3 | 0 Top Silk 0

Type
copper | | 0.035 mm | | 1 Not specified FR4 | 0

Loss Tangent 1 Material

copper core | | | | | 1 Bottom Solder Paste 4.5

0.035 mm | | | | 0.02 Not specified 0

0.01 mm | | | 3.3 | 0
0 mm | | 1
0 mm | | | 0

Id: 1/1 Title: SWC - Encoder PCB

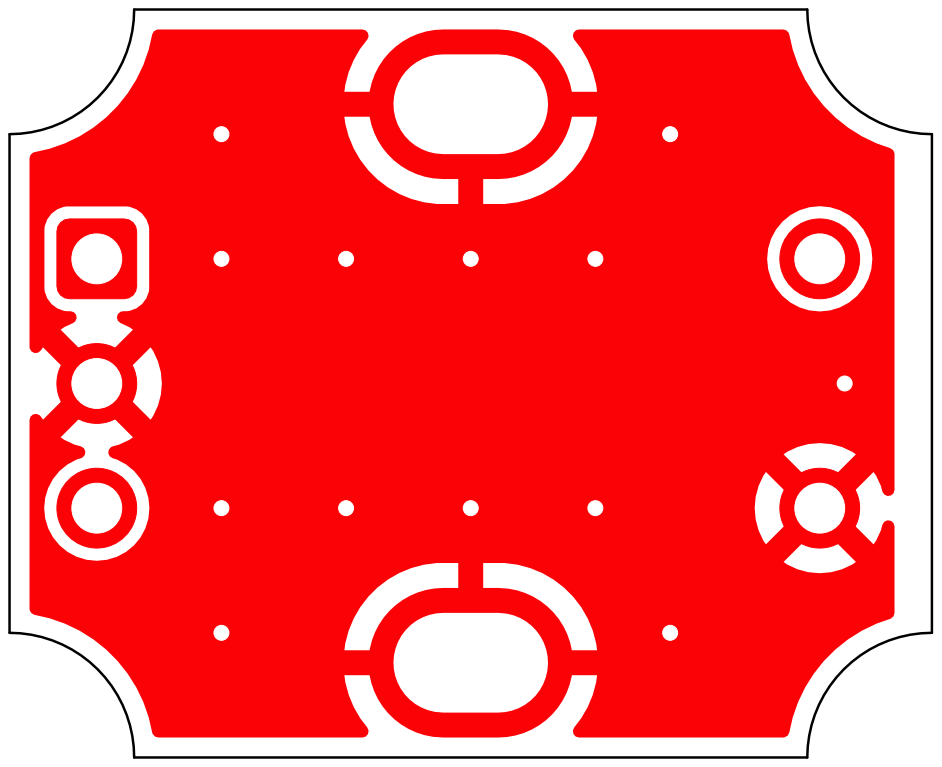
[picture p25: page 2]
6 ABCD; ABCD Date: 27-11-2025 KiCad; E.D.A. 8.0.8 Size: A4; Rev:; Pounamu; Electronics Board2Pdf:; FrontCU -; Page 2/9

File: SWC_Encoder_PCB_RevB.kicad_pcb Sheet: FrontCU
Id: 1/1 Title: SWC - Encoder PCB

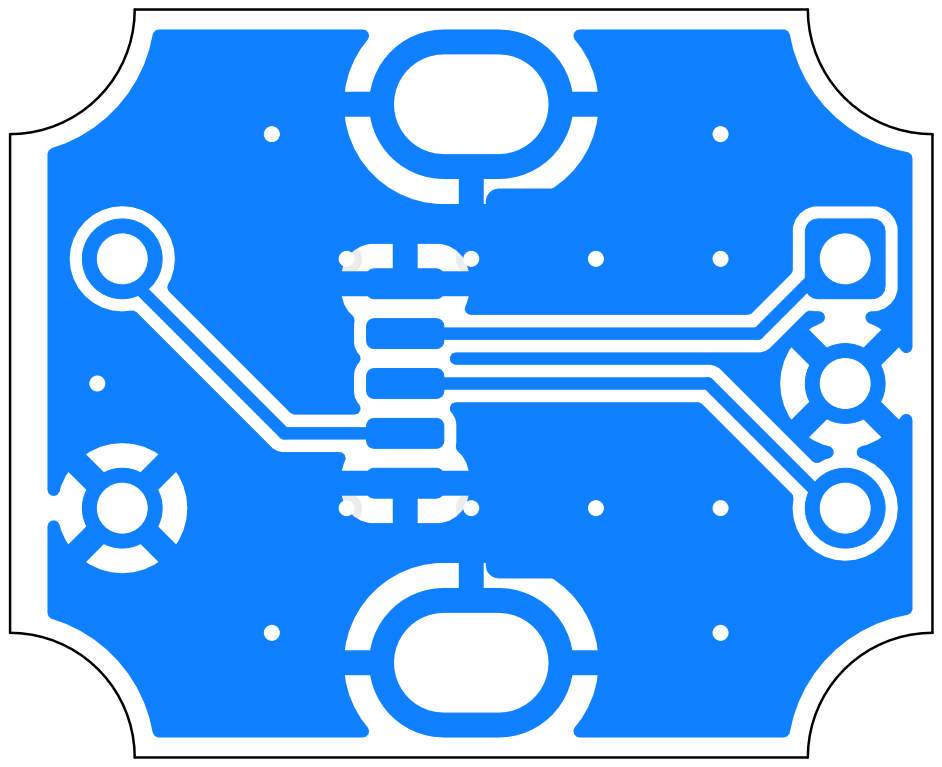
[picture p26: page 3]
6 ABCD; ABCD Date: 27-11-2025 KiCad; E.D.A. 8.0.8 Size: A4; Rev:; Pounamu; Electronics Board2Pdf:; BackCU -; Page 3/9

File: SWC_Encoder_PCB_RevB.kicad_pcb Sheet: BackCU
Id: 1/1 Title: SWC - Encoder PCB

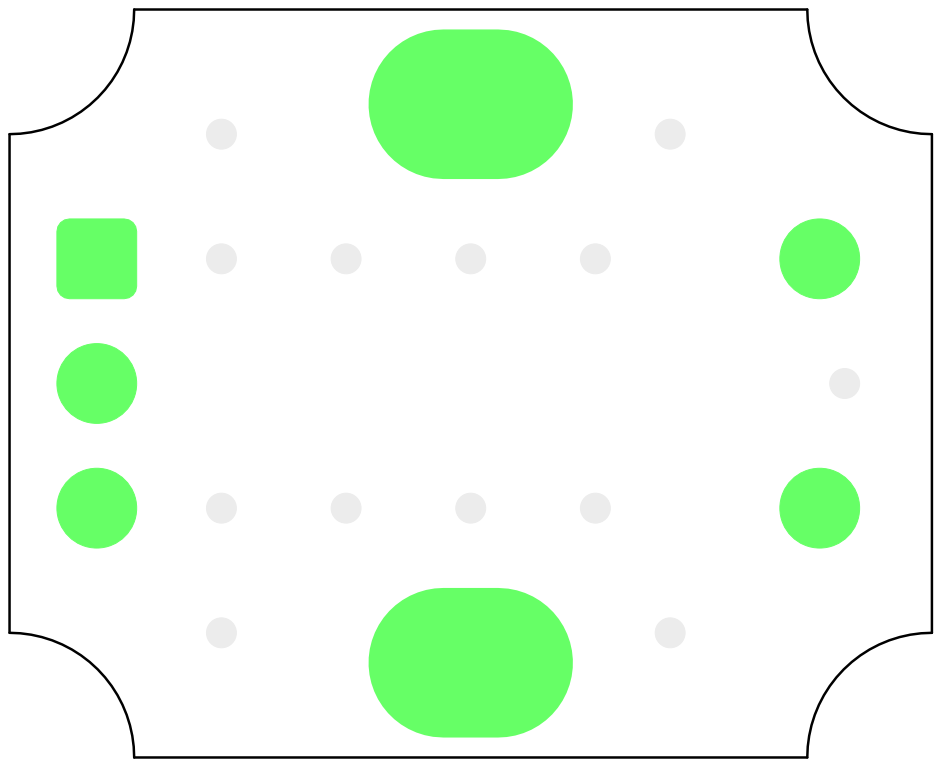
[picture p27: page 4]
6 ABCD; ABCD Date: 27-11-2025 KiCad; E.D.A. 8.0.8 Size: A4; Rev:; File: SWC_Encoder_PCB_RevB.kicad_pcb Sheet: FrontMask Pounamu; Electronics Board2Pdf:; FrontMask; Page 4/9

Id: 1/1 Title: SWC - Encoder PCB

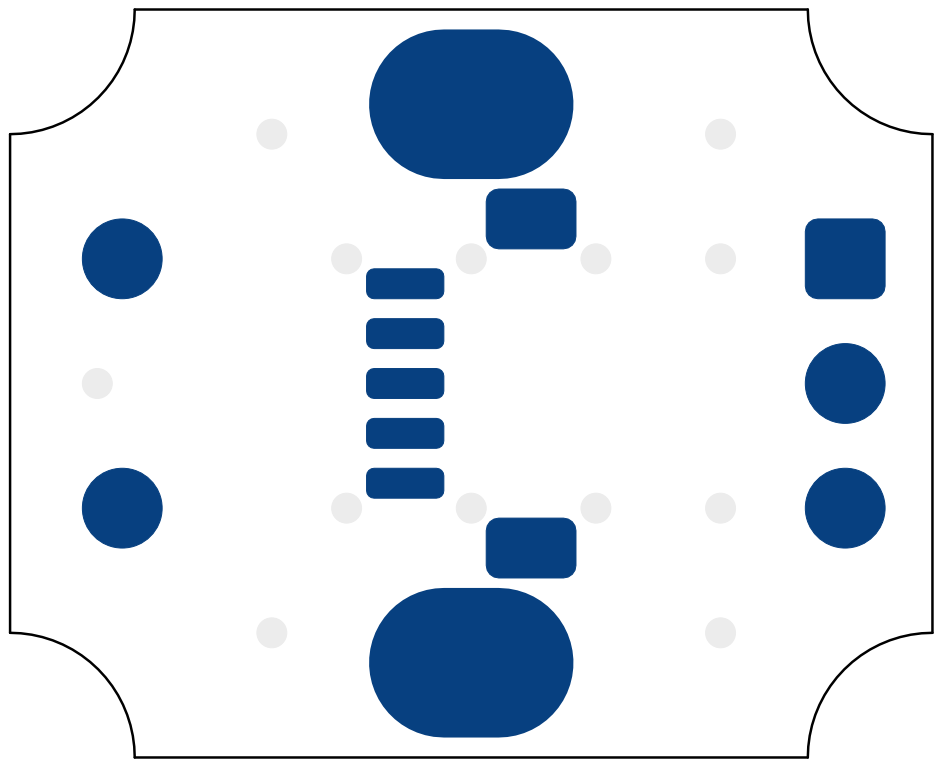
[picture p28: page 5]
6 ABCD; ABCD Date: 27-11-2025 KiCad; E.D.A. 8.0.8 Size: A4; Rev:; File: SWC_Encoder_PCB_RevB.kicad_pcb Sheet: BackMask Pounamu; Electronics Board2Pdf:; BackMask; Page 5/9

Id: 1/1 Title: SWC - Encoder PCB

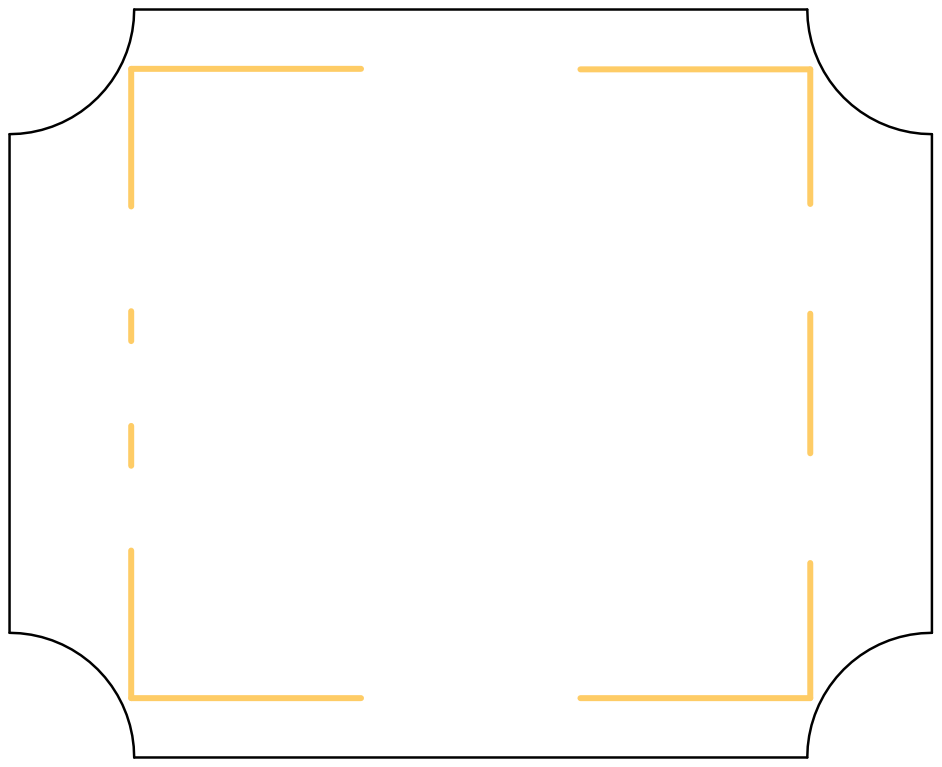
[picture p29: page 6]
6 ABCD; ABCD Date: 27-11-2025 KiCad; E.D.A. 8.0.8 Size: A4; Rev:; Pounamu; Electronics Board2Pdf:; FrontSS -; Page 6/9

File: SWC_Encoder_PCB_RevB.kicad_pcb Sheet: FrontSS
Id: 1/1 Title: SWC - Encoder PCB

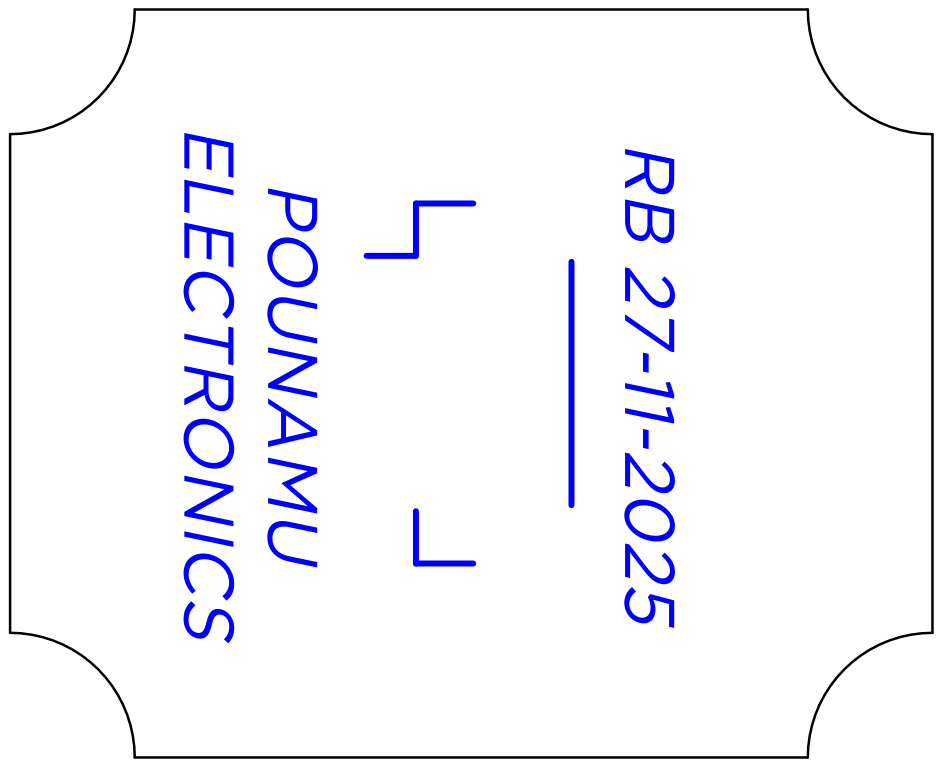
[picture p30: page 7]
6 ABCD; ABCD Date: 27-11-2025 KiCad; E.D.A. 8.0.8 Size: A4; Rev:; Pounamu; Electronics Board2Pdf:; BackSS -; Page 7/9

File: SWC_Encoder_PCB_RevB.kicad_pcb Sheet: BackSS
Id: 1/1 Title: SWC - Encoder PCB

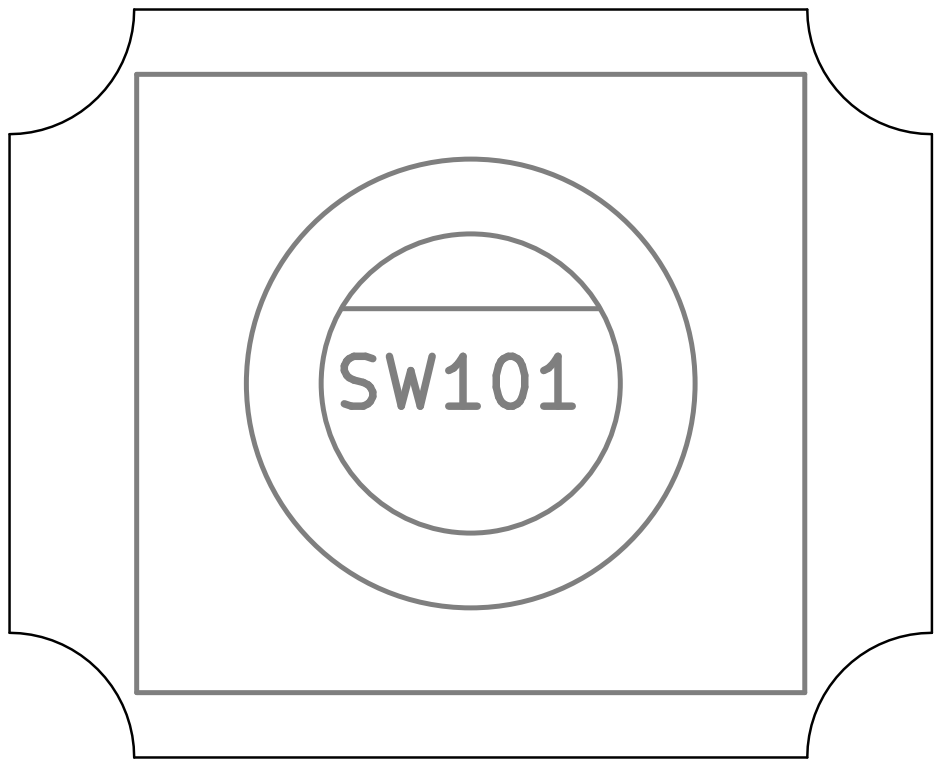
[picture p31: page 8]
6 ABCD; ABCD Date: 27-11-2025 KiCad; E.D.A. 8.0.8 Size: A4; Rev:; File: SWC_Encoder_PCB_RevB.kicad_pcb Sheet: FrontFab Pounamu; Electronics Board2Pdf:; FrontFab; Page 8/9

Id: 1/1 Title: SWC - Encoder PCB

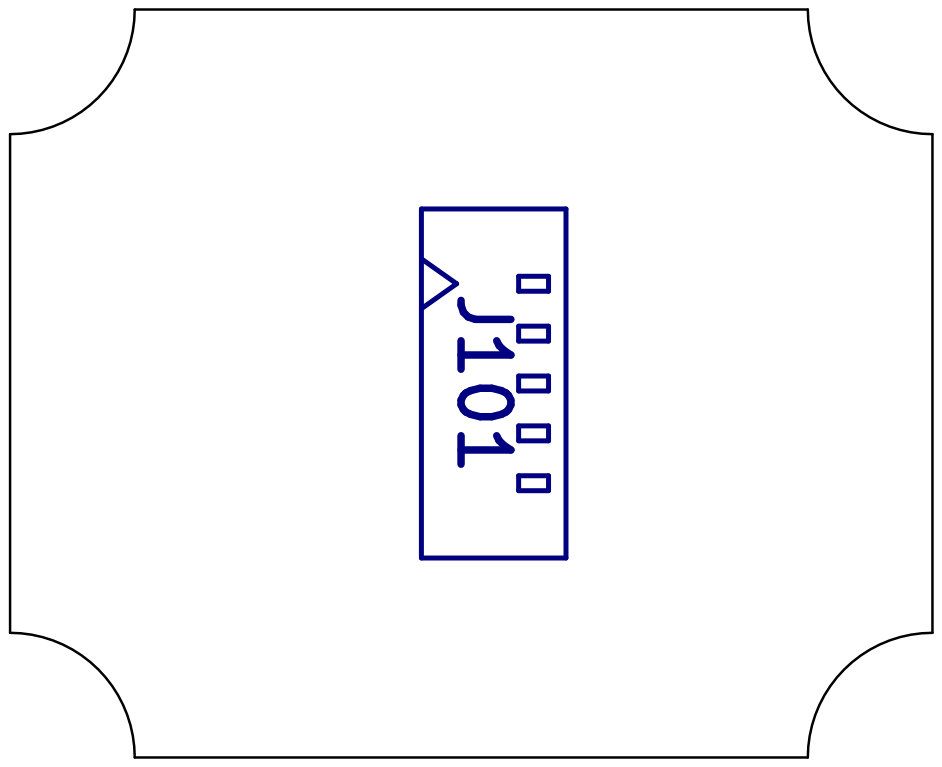
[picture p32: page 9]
6 ABCD; ABCD Date: 27-11-2025 KiCad; E.D.A. 8.0.8 Size: A4; Rev:; File: SWC_Encoder_PCB_RevB.kicad_pcb Sheet: BackFab Pounamu; Electronics Board2Pdf:; BackFab; Page 9/9 J101

Id: 1/1 Title: SWC - Encoder PCB

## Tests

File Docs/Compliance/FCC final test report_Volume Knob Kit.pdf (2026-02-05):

Report No.: CTB26011913201E01

Ver. A.1 | Tel: 4008-707-283 | Web: http://www.ctb-lab.net | Page 1 / 20

# EMC TEST REPORT

Test item description: Volume Knob Kit Trademark(s): /
Model/Type reference: RE_SWC S/N: /
Report No.: CTB26011913201E01
Applicant’s name: Pounamu Electronics
Address: 22 Peony Mews, Oteha, Auckland 0632, New Zealand Manufacturer: Pounamu Electronics
Address: 22 Peony Mews, Oteha, Auckland 0632, New Zealand
Prepared by: Shenzhen CTB Testing Technology Co., Ltd.
Address: 1&2/F., Building A, No.26, Xinhe Road, Xinqiao, Xinqiao Street, Bao'an District, Shenzhen, Guangdong, China Sample No.: 26011913201
Date of Receipt: Jan. 19, 2026
Date of Test(s): Jan. 19, 2026 ~ Jan. 20, 2026
Date of Issue: Jan. 30, 2026
Test Standard(s): 47 CFR Part 15 Subchapter B, ANSI C63.4: 2014
Test Result: Pass
In the configuration tested, the EUT complied with the standards specified above.

Note: If there is any objection to the inspection results in this report, please submit a written report to the company within 15 days from the date of receiving the report. The test report is effective only with both signature and specialized stamp. This result(s) shown in this report refer only to the sample(s) tested. The tested sample(s) and the sample information are provided by the applicant. The authenticity, accuracy, and completeness of the provided information are the sole responsibility of the applicant. Without written approval of Shenzhen CTB Testing Technology Co., Ltd. this report can’t be reproduced except in full. The result decision rules of our laboratory are based solely on the direct comparison between the actual measured values of test results and the standard limits, without considering the measurement uncertainty.“” indicates the testing items were fulfilled by subcontracted lab. “” indicates the items are not in CNAS accreditation scope.

Compiled by: | Reviewed by: | Approved by:
Ice Chen | Bin Mei | Rita Xiao

Ver. A.1 | Tel: 4008-707-283 | Web: http://www.ctb-lab.net | Page 2 / 20

Table of Contents

Ver. A.1 | Tel: 4008-707-283 | Web: http://www.ctb-lab.net | Page 3 / 20

### 1. Description of version

Report No. | Issue Date | Description | Approved
CTB26011913201E01 | Jan. 30, 2026 | Original | Valid

Ver. A.1 | Tel: 4008-707-283 | Web: http://www.ctb-lab.net | Page 4 / 20

### 2. Test summary

Test procedures according to the technical standards:
Standard | Test Item | Test Result
§15.107 | Conducted Emission | PASS
§15.109 | Radiated Emission | PASS

Ver. A.1 | Tel: 4008-707-283 | Web: http://www.ctb-lab.net | Page 5 / 20

### 3. Measurement uncertainty

The reported uncertainty of measurement y ± U, where expended uncertainty U is based on a standard uncertainty multiplied by a coverage factor of k=2, providing a level of confidence of approximately 95 %

Test Item | Frequency | Expanded Uncertainty (ULab)
Conducted Emission | 150 kHz to 30 MHz | No.1 ± 3.4 dB No.2 ± 3.5 dB
Radiated Emission | 30 MHz to 1000 MHz | No.1 ± 4.9 dB No.2 ± 4.6 dB
Radiated Emission | 1000 MHz to 6000 MHz | No.1 ± 4.9 dB, No.2 ± 4.8 dB

Ver. A.1 | Tel: 4008-707-283 | Web: http://www.ctb-lab.net | Page 6 / 20

### 4. General information 4.1. Description of EUT

Test item description | Volume Knob Kit
Trademark(s) | /
Model/Type reference | RE_SWC
Serial Model No. | /
Model Difference | /
Rated Power | /
Rated Voltage& current | DC 5V 100mA from adapter(AC 230V/50Hz) or DC 5V from Laptop
Highest Internal Frequency | 48MHz
Configuration | Table-top Floor-standing
Classification | Class A Class B
The highest frequency of the internal sources of the EUT | below 1.705 MHz, the measurement shall only be made up to 30 MHz. between 1.705 MHz and 108 MHz, the measurement shall only be made up to 1 GHz. between 108 MHz and 500 MHz, the measurement shall only be made up to 2 GHz. between 500 MHz and 1 GHz, the measurement shall only be made up to 5 GHz. above 1 GHz, the measurement shall be made up to 5th harmonic of the highest frequency or 40 GHz, whichever is lower.
Adapter Information | /
Note: The above EUT information is declared by manufacturer and for more detailed features description, please refer to the manufacturer’s specifications or the User's Manual.

### 4.2. Description of accessory device

Description | Manufacturer | Model | Specification | Note
Adapter | HUAWEI | HW-050100C01 | Input: 100-240V~ 50/60Hz 0.2A Output: 5V 1A | Applicant CTB
Laptop | Lenovo | 21CU-A0F0CD | / | Applicant CTB

External I/O Cable
Cable Description | Shielded Type | Ferrite Core | Length(m) | Note
/ | Shielded Non-shielded | Yes No | / | Applicant CTB

### 4.3. Test conditions

Temperature: 15-25℃
Relative Humidity: 30-60%RH Atmospheric pressure: 800hPa-1060hPa

Ver. A.1 | Tel: 4008-707-283 | Web: http://www.ctb-lab.net | Page 7 / 20

### 4.4. Block diagram of EUT configuration

### 4.5. Operating condition of EUT

The test system was pre-tested based on the consideration of all possible combinations of EUT operation modes according to test plan. Each of these EUT operation mode(s) or test configuration mode(s) mentioned above was evaluated respectively. All test mode(s) and condition(s) mentioned were considered and evaluated respectively by performing full tests, (*)the worst data were recorded and reported.

Pretest Test Mode | Description | Test Voltage
Mode 1* | Working | AC 120V/60Hz
Mode 2* | Working | DC 5V

Conducted emission test
Final Test Mode | Description | Test Voltage
Mode 1* | Working | AC 120V/60Hz

Radiated emission test
Final Test Mode | Description | Test Voltage
Mode 2* | Working | DC 5V
AC Mains | Adapter | EUT

Ver. A.1 | Tel: 4008-707-283 | Web: http://www.ctb-lab.net | Page 8 / 20

### 5. List of Test and Measurement Instruments

No.1 Continuous disturbance
No. | Equipment | Manufacturer | Model No. | Serial No. | Firmware version | Calibrated until
1 | 843 Shield Room | C/ R/ T | 843 | / | / | 2027/6/21
2 | LISN | ROHDE&SCHWARZ | ESH3-Z5 | 100318 | / | 2026/5/21
3 | Pulse limiter | ROHDE&SCHWARZ | ESH3-Z2 | 0357.8810.54-1 02700-NB | / | 2026/5/21
4 | EMI TEST RECEIVER | R&S | ESCI | 100428 | V4.42.SP3 | 2026/5/21
5 | Coaxial cable | Agilent | UCE500-SMNM-1. 5M | / | / | 2026/5/21
6 | ISN | Schwarzbeck | NTFM8158 | 183 | / | 2026/6/17
7 | ISN | Schwarzbeck | CAT5 8158 | 473 | / | 2026/6/17
8 | Voltage Probe | Schwarzbeck | TK 9420 | 01189 | / | 2026/9/18
9 | EMI test software | Frad | EZ-EMC | Ver/ EMC-con3A1/1 | / | /
10 | Current Probe | FCC | F-52B | 199453 | / | 2026/5/23

Radiated emission(No.1 Chamber)
No. | Equipment | Manufacturer | Model No. | Serial No. | Firmware version | Calibrated until
1 | 966 Chamber | C/ R/ T | 966 | / | / | 2027/6/21
2 | Double Ridged Broadband Horn Antenna | Schwarzbeck | BBHA 9120 D | 01911 | / | 2026/6/1
3 | TRILOG Broadband Antenna | Schwarzbeck | VULB 9168 | 00869 | / | 2026/6/28
4 | Preamplifier | Agilent | 8449B | 3008A01838 | / | 2026/6/3
5 | Amplifier | HP | 8447E | 2945A02747 | / | 2026/5/23
6 | 6dB attenuator | Agilent | 6dB (8491B) | MY39170906 | / | 2026/5/23
7 | loop antenna | Schwarzbeck | FMZB 1519B | 1519B-224 | / | 2026/6/1
8 | EMI TEST RECEIVER | ROHDE&SCHWA RZ | ESPI | 100362 | RF_ATTEN_7 （104489/003） | 2026/5/23
9 | Spectrum Analyzer | KEYSIGHT | N9020A | MY51289897 | A.14.16 | 2026/5/22
10 | 26.5G cable | ETS | RFC-SNS-100-N MS-80 | / | / | 2026/5/23
11 | 26.5G cable | ETS | RFC-SN-100-NM S-20 | / | / | 2026/5/23
12 | 26.5G cable | ETS | RFC-SNS-100-S | / | / | 2026/5/23

Ver. A.1 | Tel: 4008-707-283 | Web: http://www.ctb-lab.net | Page 9 / 20
| | | MS-20
13 | 26.5G cable | ETS | RFC-NNS-100-N MS-300 | / | / | 2026/5/23
14 | EMI test software | Frad | EZ-EMC | Ver/ FA-03A2 RE | / | /

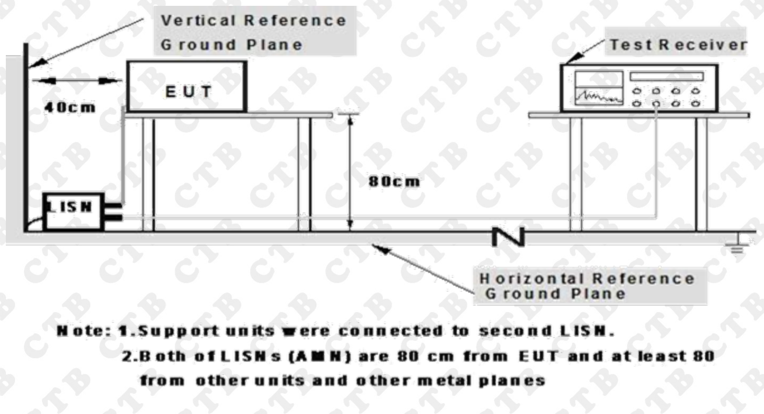
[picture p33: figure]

Ver. A.1 | Tel: 4008-707-283 | Web: http://www.ctb-lab.net | Page 10 / 20

### 6. Conducted Emission 6.1. Limit

Except for Class A devices:
Frequency of emission (MHz) | Conducted limit (dBμV)
Quasi-peak | Average
0.15-0.5 | 66 to 56* | 56 to 46*
0.5-5 | 56 | 46
5-30 | 60 | 50
Note: Decreases with the logarithm of the frequency.

For Class A devices:
Frequency of emission (MHz) | Conducted limit (dBμV)
Quasi-peak | Average
0.15-0.5 | 79 | 66
0.5-30 | 73 | 60

### 6.2. Test setup

The setup of EUT is according with ANSI C63.4 measurement procedure. Specification used with FCC Part 15 limits.

### 6.3. EMI test receiver setup

Frequency Range | 9kHz-30MHz
Resolution Bandwidth | 200Hz (9kHz-150kHz) 9kHz (150kHz-30MHz)

### 6.4. Test procedure

1. Measurement was performed in shielded room, and instruments used were followed clause 4 of ANSI C63.4.
2. Detailed test procedure was following clause 7 of ANSI C63.4.
3. Frequency range 150kHz – 30MHz was checked and EMI receiver measurement bandwidth was set to 9 kHz.

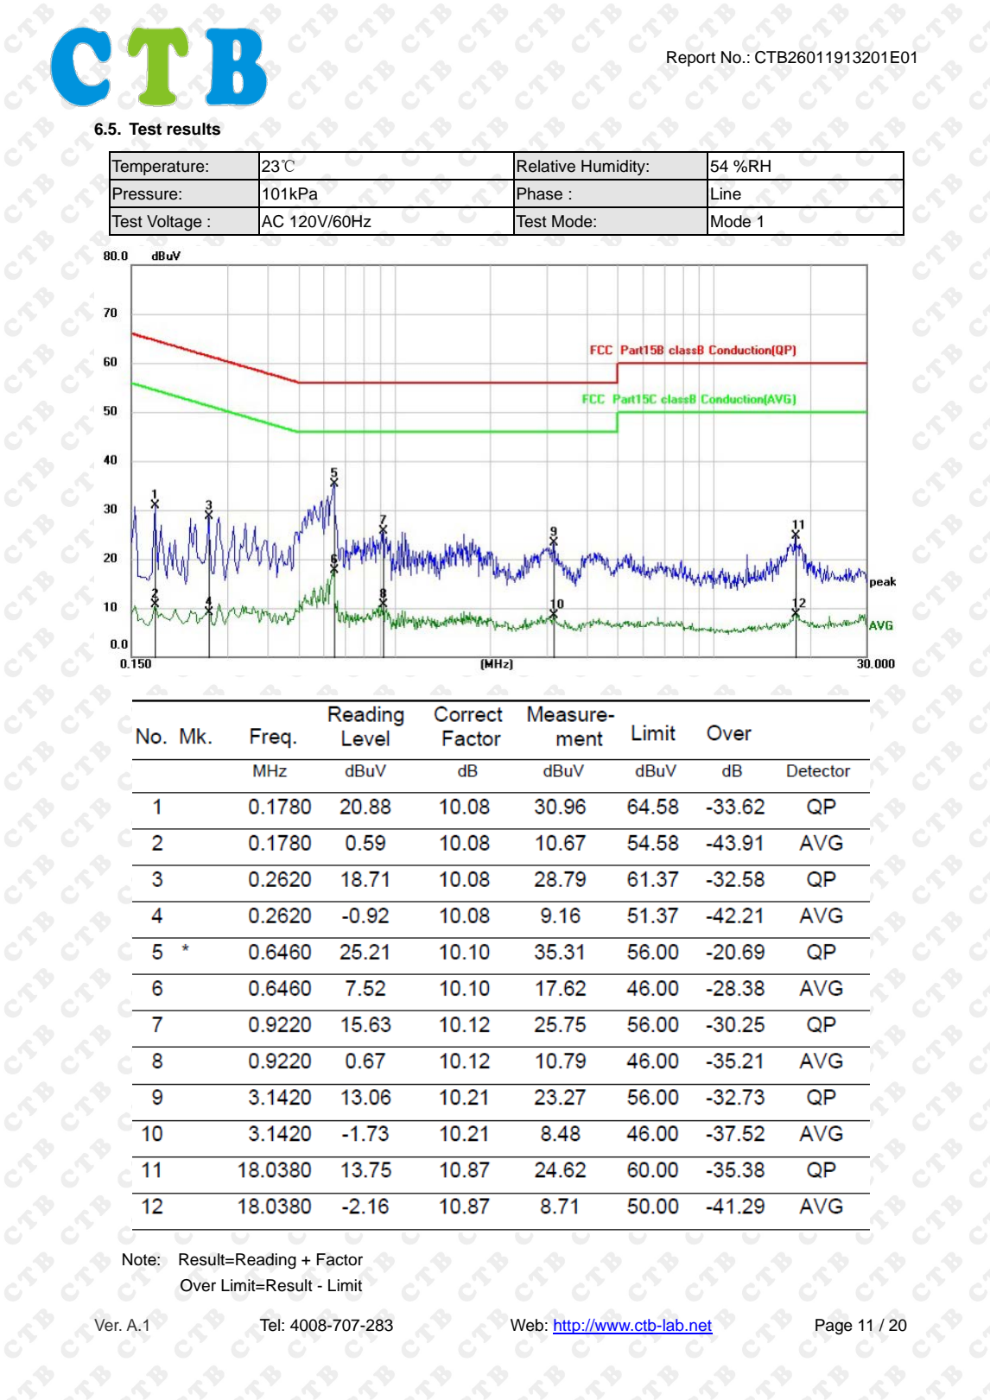
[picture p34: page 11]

Ver. A.1 | Tel: 4008-707-283 | Web: http://www.ctb-lab.net | Page 11 / 20

### 6.5. Test results

Temperature: | 23℃ | Relative Humidity: | 54 %RH
Pressure: | 101kPa | Phase : | Line
Test Voltage : | AC 120V/60Hz | Test Mode: | Mode 1

Note: Result=Reading + Factor Over Limit=Result - Limit

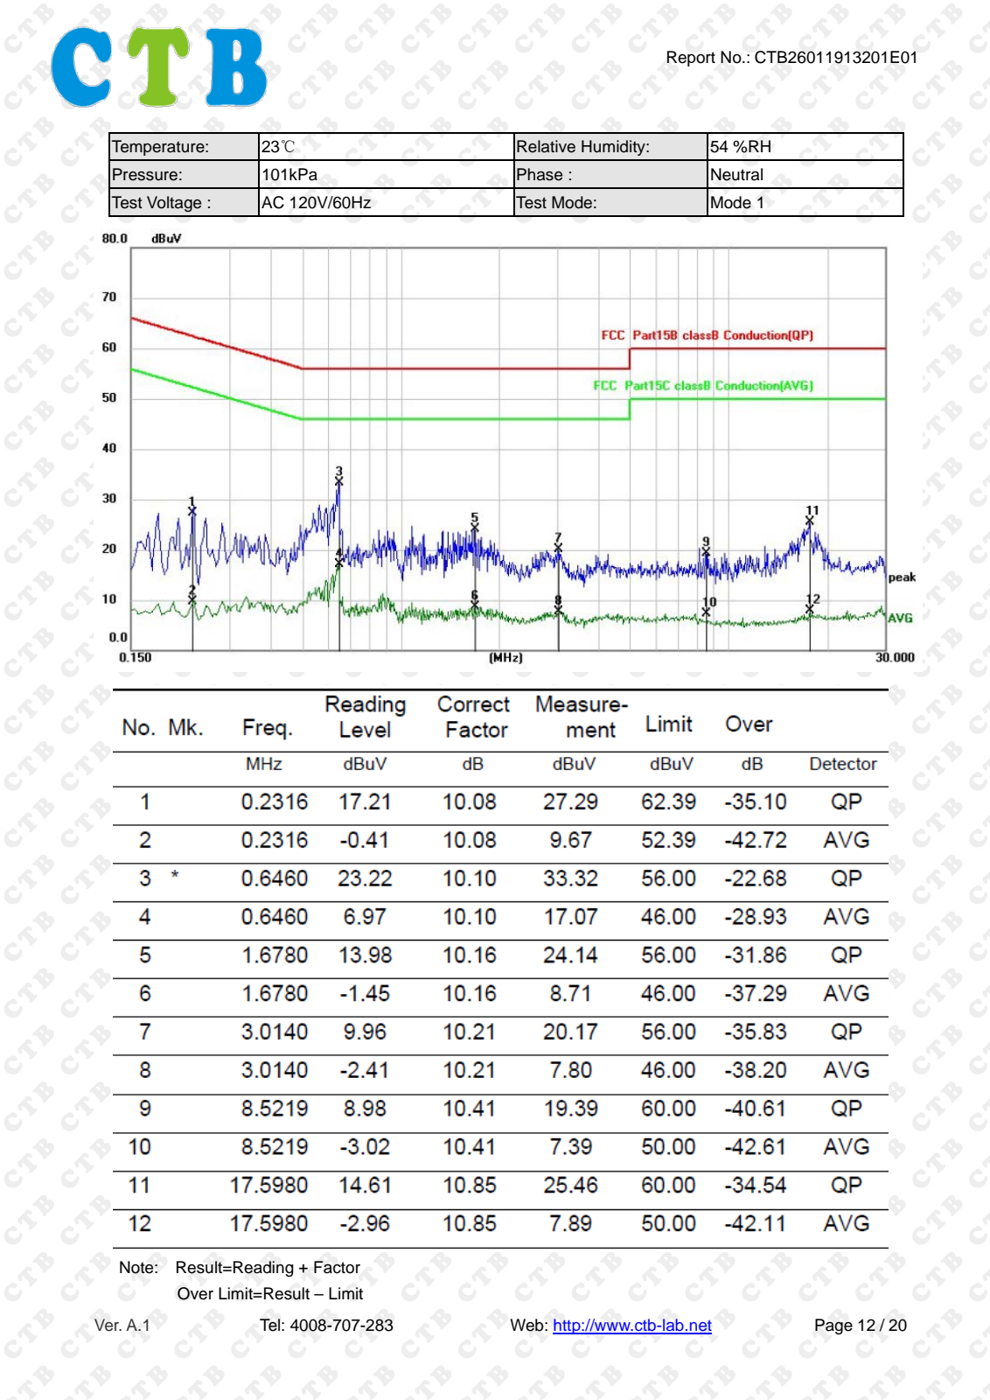
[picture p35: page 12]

Ver. A.1 | Tel: 4008-707-283 | Web: http://www.ctb-lab.net | Page 12 / 20
Temperature: | 23℃ | Relative Humidity: | 54 %RH
Pressure: | 101kPa | Phase : | Neutral
Test Voltage : | AC 120V/60Hz | Test Mode: | Mode 1

Note: Result=Reading + Factor Over Limit=Result – Limit

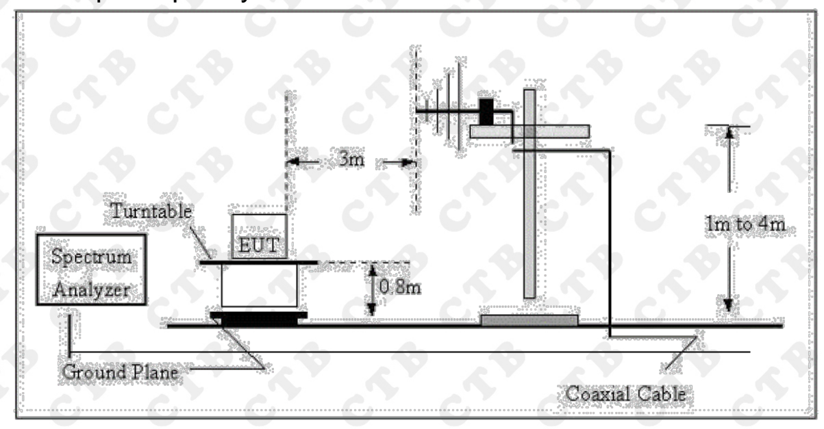
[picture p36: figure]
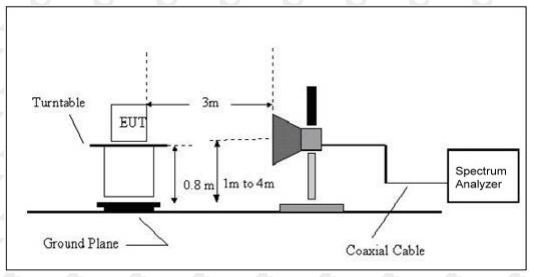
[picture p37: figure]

Ver. A.1 | Tel: 4008-707-283 | Web: http://www.ctb-lab.net | Page 13 / 20

### 7. Radiated emissions 7.1. Limit

Except for Class A devices (at 3m):
Frequency of emission (MHz) | Field strength (microvolts/meter)
(microvolts/meter) | (dBμV/m)
30-88 | 100 | 40
88-216 | 150 | 43.5
216-960 | 200 | 46
Above 960 | 500 | 54

For Class A devices (at 10m):
Frequency of emission (MHz) | Field strength (microvolts/meter)
(microvolts/meter) | (dBμV/m)
30-88 | 90 | 39
88-216 | 150 | 43.5
216-960 | 210 | 46.4
Above 960 | 300 | 49.5

### 7.2. Test setup

Radiated Emission Test Set-Up Frequency Below 1 GHz

Radiated Emission Test Set-Up Frequency Above 1GHz

The radiated tests were performed in 3 meter Charmber test site, using the setup accordance with the ANSI C63.4:2014.

Ver. A.1 | Tel: 4008-707-283 | Web: http://www.ctb-lab.net | Page 14 / 20

### 7.3. EMI test receiver setup and spectrum analyzer setup

During the radiated emission test, the EMI test receiver and Spectrum Analyzer were set with the following configurations:
Frequency Range | RBW | Video B/W | IF B/W | Detector
30MHz-1000MHz | 100kHz | 300kHz | 120kHz | QP
Above 1GHz | 1MHz | 3MHz | / | PK
| 1MHz | 10Hz | / | AVG

### 7.4. Test procedure

1. The measurement was performed in a semi-anechoic chamber, and instruments used were followed clause 4 of ANSI C63.4
2. Detailed test procedure was following clause 8 of ANSI C63.4.

### 7.5. Corrected Amplitude & Margin Calculation

1. The Corrected Amplitude is calculated by adding the Antenna Factor and Cable Loss, and subtracting the Amplifier Gain from the Meter Reading. The basic equation is as follows:
Corrected Amplitude = Meter Reading + Antenna Factor + Cable Loss - Amplifier Gain
2. The “Margin” column of the following data tables indicates the degree of compliance with the applicable limit. For example, a margin of 7dB means the emission is 7dB below the limit. The equation for margin calculation is as follows:
Margin = Limit – Corrected Amplitude

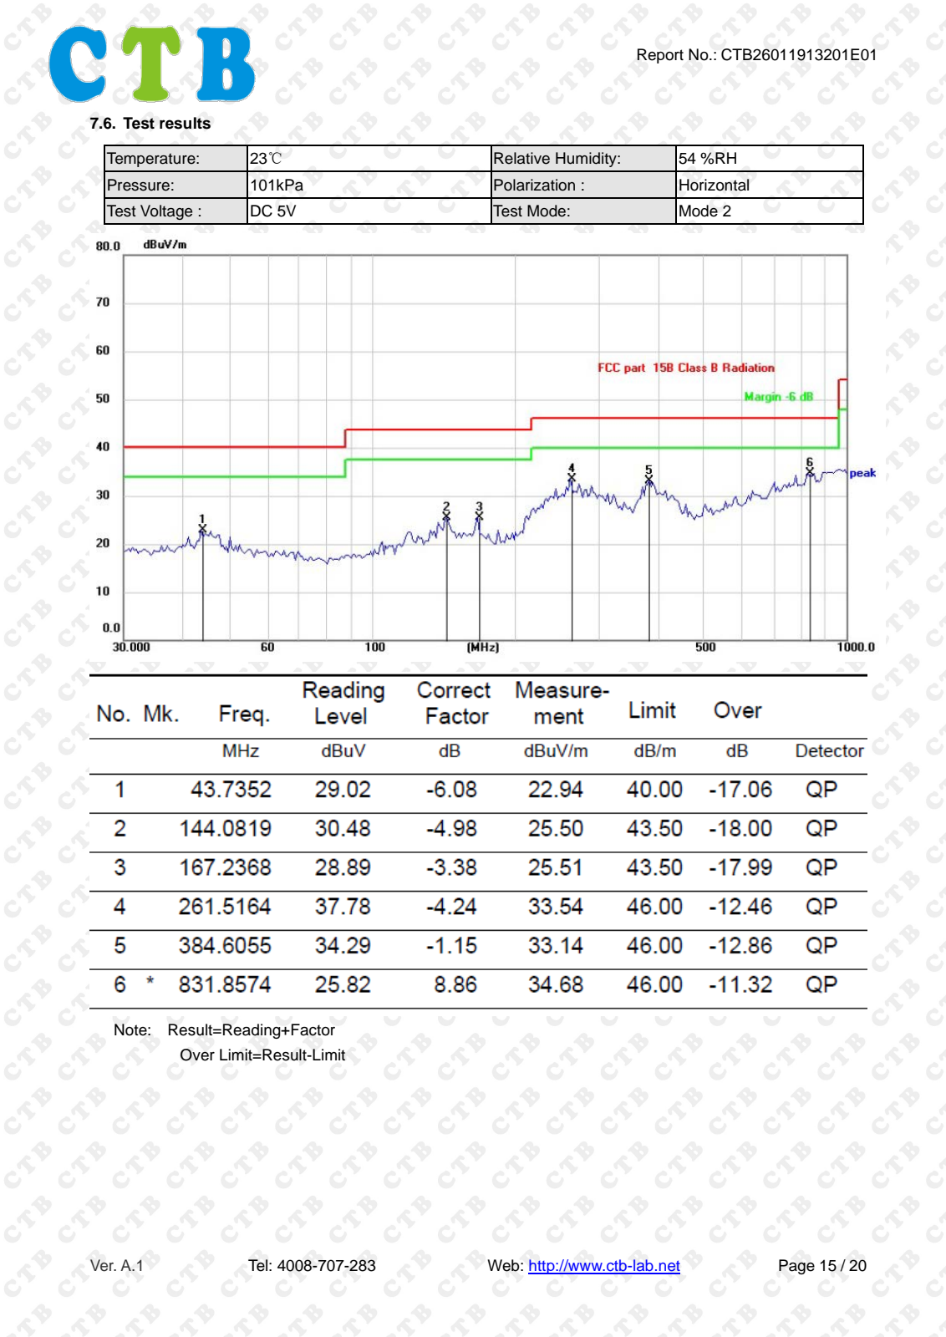
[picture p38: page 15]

Ver. A.1 | Tel: 4008-707-283 | Web: http://www.ctb-lab.net | Page 15 / 20

### 7.6. Test results

Temperature: | 23℃ | Relative Humidity: | 54 %RH
Pressure: | 101kPa | Polarization : | Horizontal
Test Voltage : | DC 5V | Test Mode: | Mode 2

Note: Result=Reading+Factor Over Limit=Result-Limit

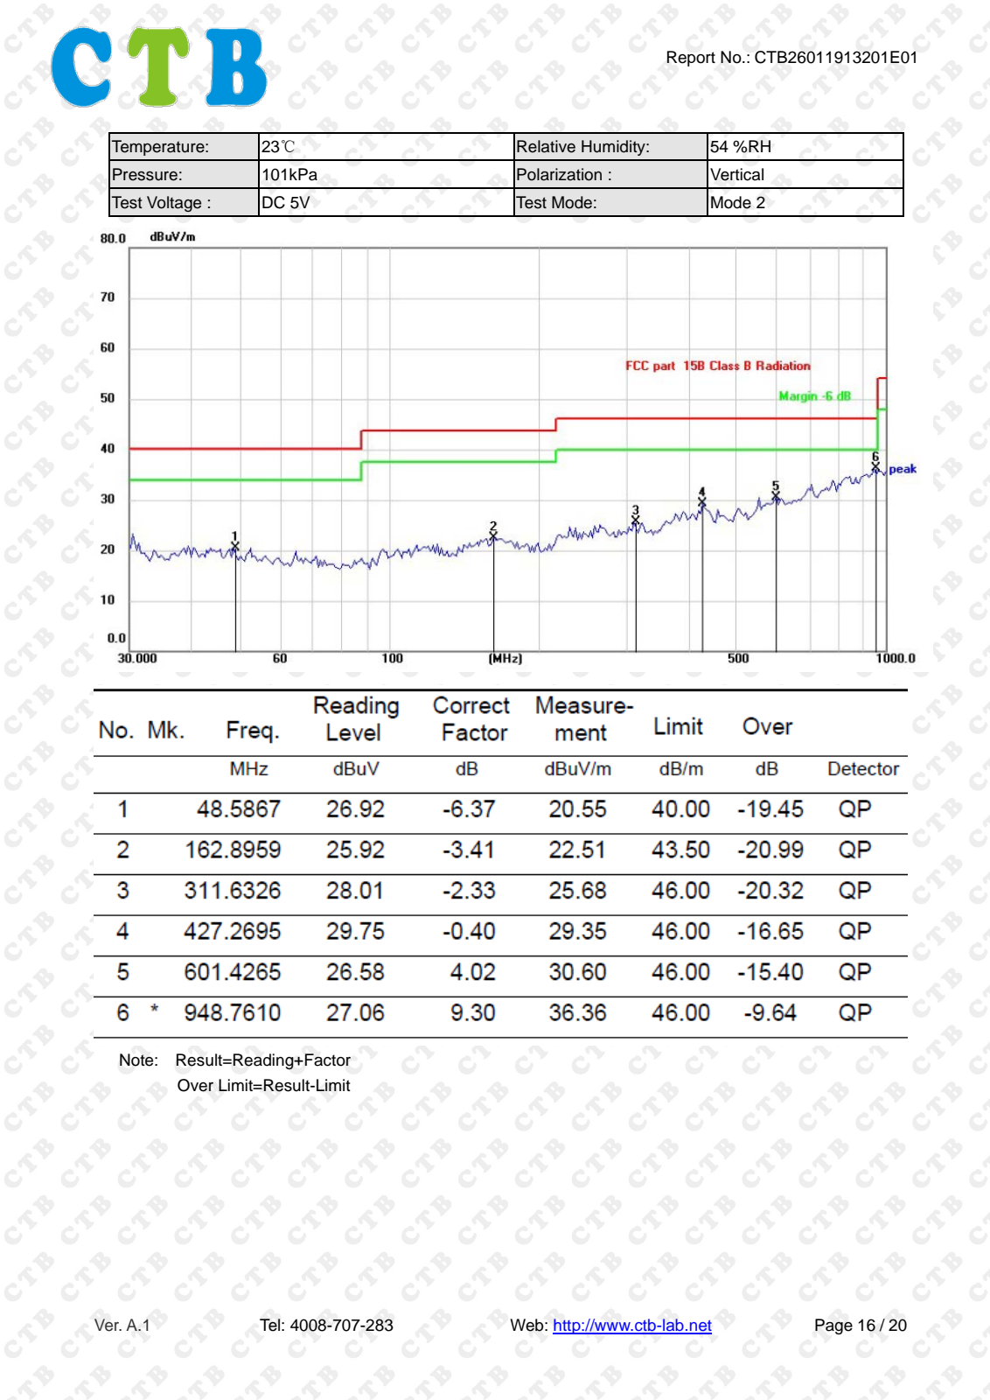
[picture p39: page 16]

Ver. A.1 | Tel: 4008-707-283 | Web: http://www.ctb-lab.net | Page 16 / 20
Temperature: | 23℃ | Relative Humidity: | 54 %RH
Pressure: | 101kPa | Polarization : | Vertical
Test Voltage : | DC 5V | Test Mode: | Mode 2

Note: Result=Reading+Factor Over Limit=Result-Limit

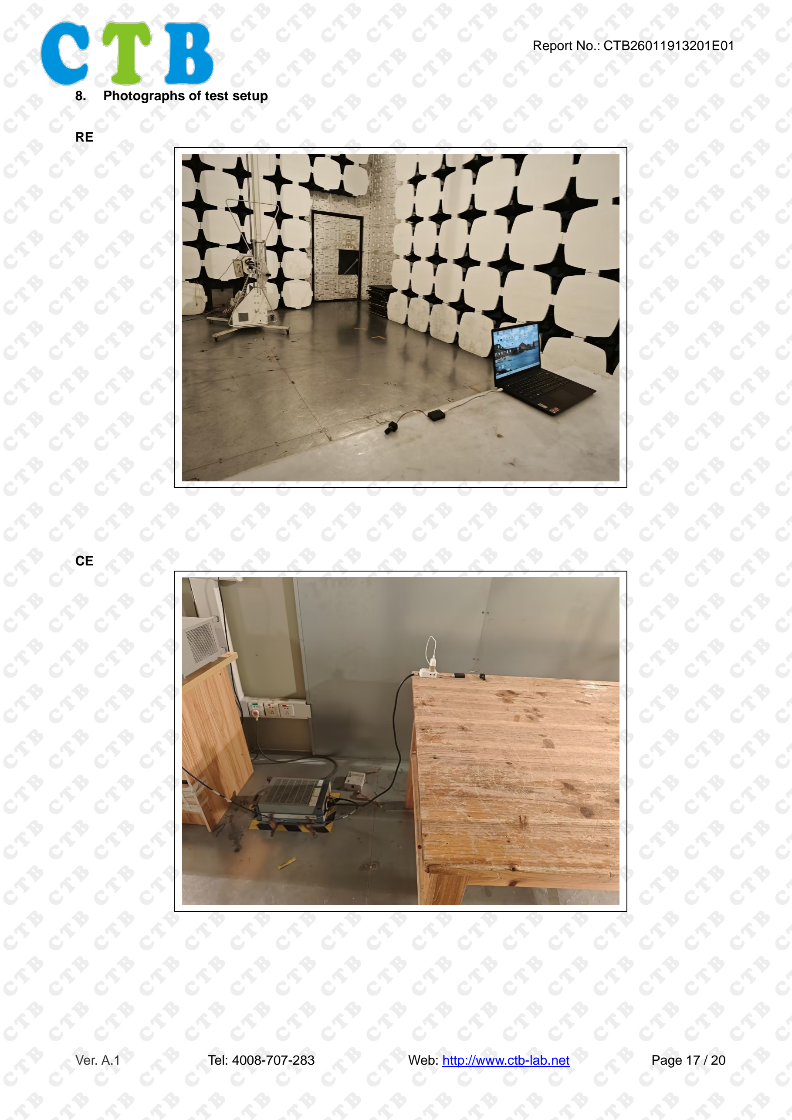
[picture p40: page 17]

Ver. A.1 | Tel: 4008-707-283 | Web: http://www.ctb-lab.net | Page 17 / 20

### 8. Photographs of test setup

RE

CE

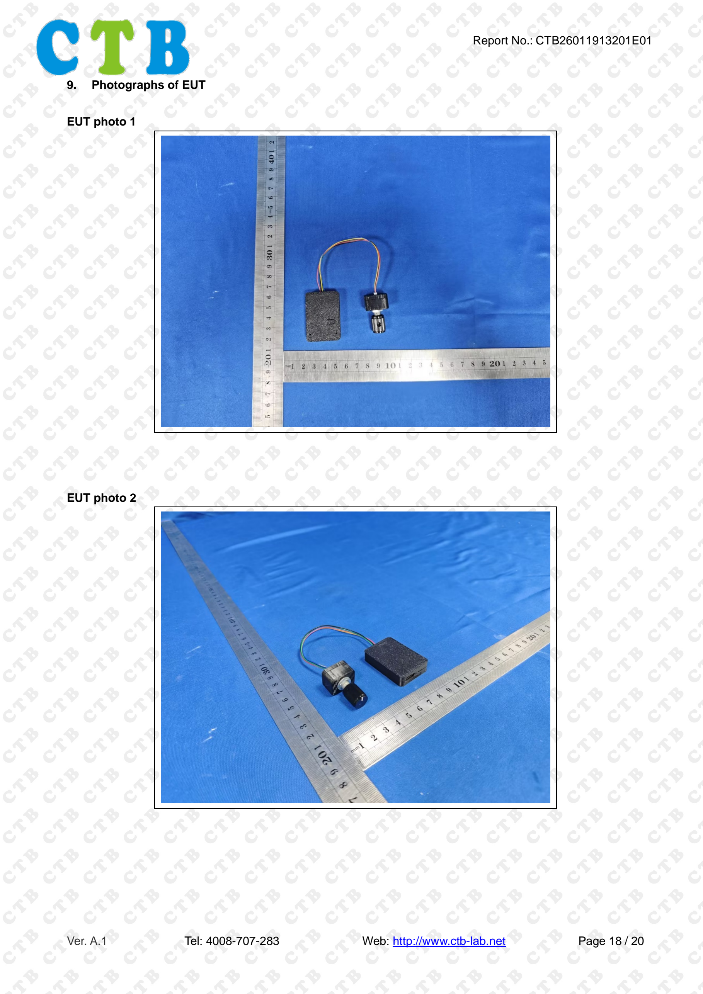
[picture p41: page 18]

Ver. A.1 | Tel: 4008-707-283 | Web: http://www.ctb-lab.net | Page 18 / 20

### 9. Photographs of EUT

EUT photo 1

EUT photo 2

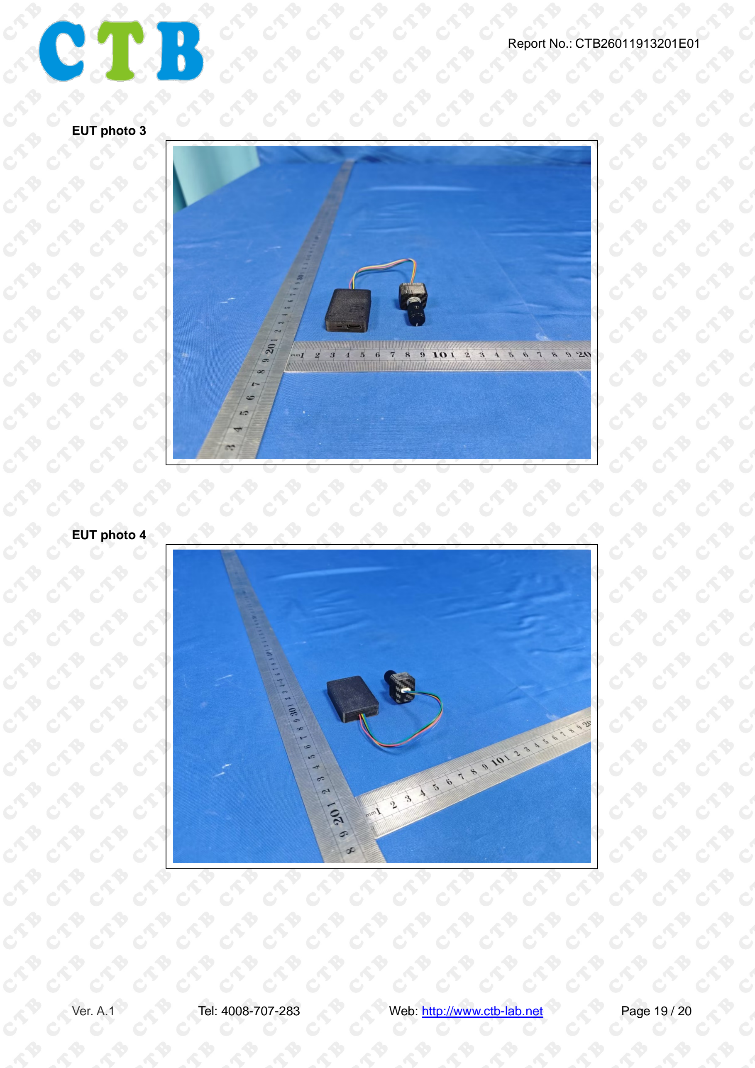
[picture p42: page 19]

Ver. A.1 | Tel: 4008-707-283 | Web: http://www.ctb-lab.net | Page 19 / 20

EUT photo 3

EUT photo 4


Ver. A.1 | Tel: 4008-707-283 | Web: http://www.ctb-lab.net | Page 20 / 20

EUT photo 5

***End of report***

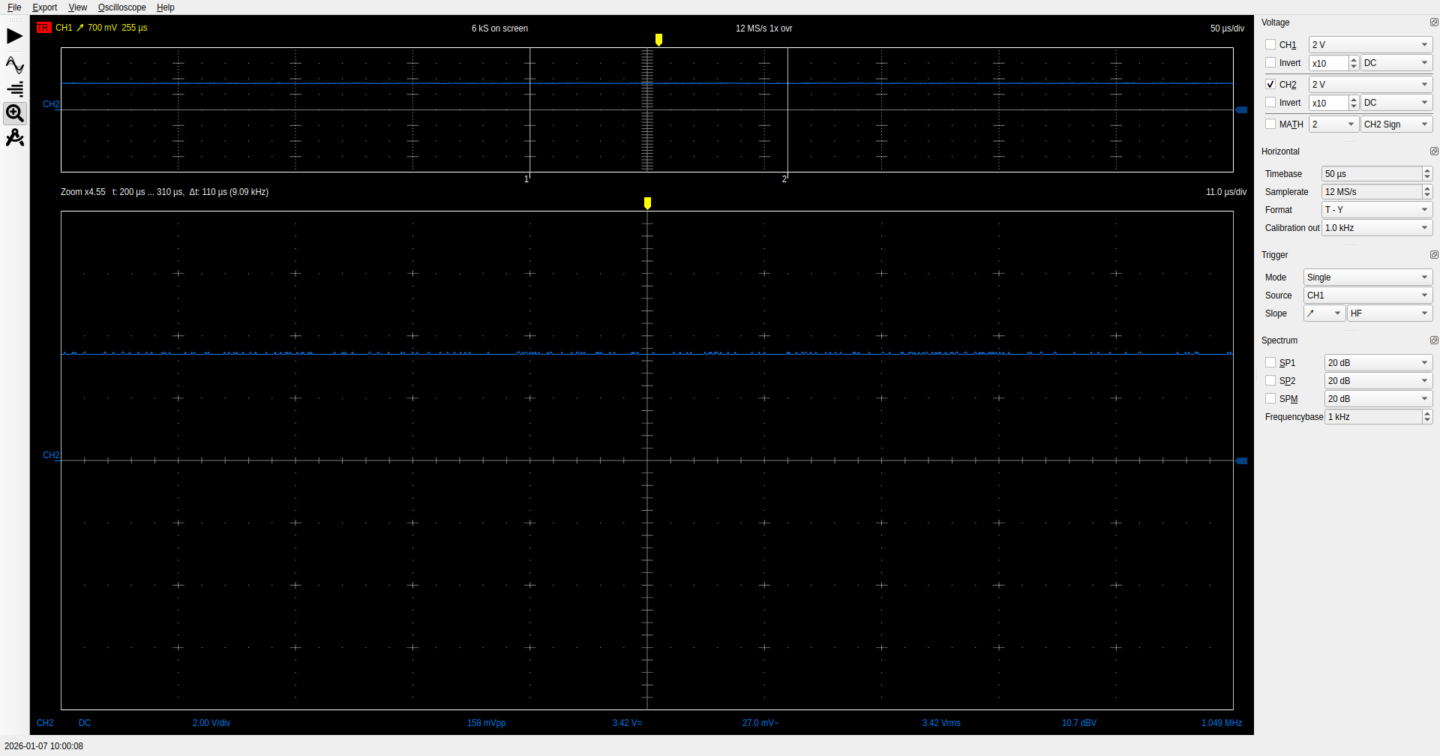
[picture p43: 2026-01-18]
Images/BoardBringup/3V3Reg.png

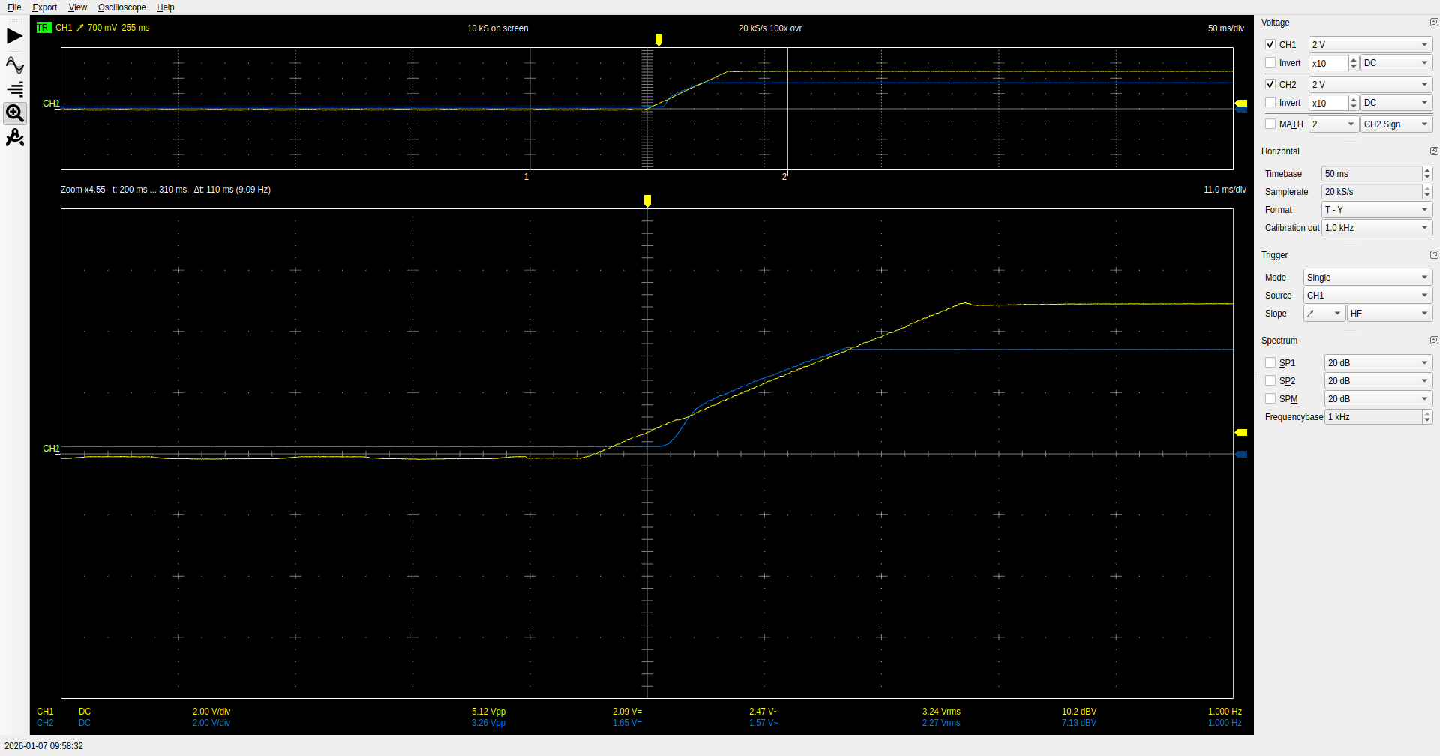
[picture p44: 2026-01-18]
Images/BoardBringup/RegBoot.png

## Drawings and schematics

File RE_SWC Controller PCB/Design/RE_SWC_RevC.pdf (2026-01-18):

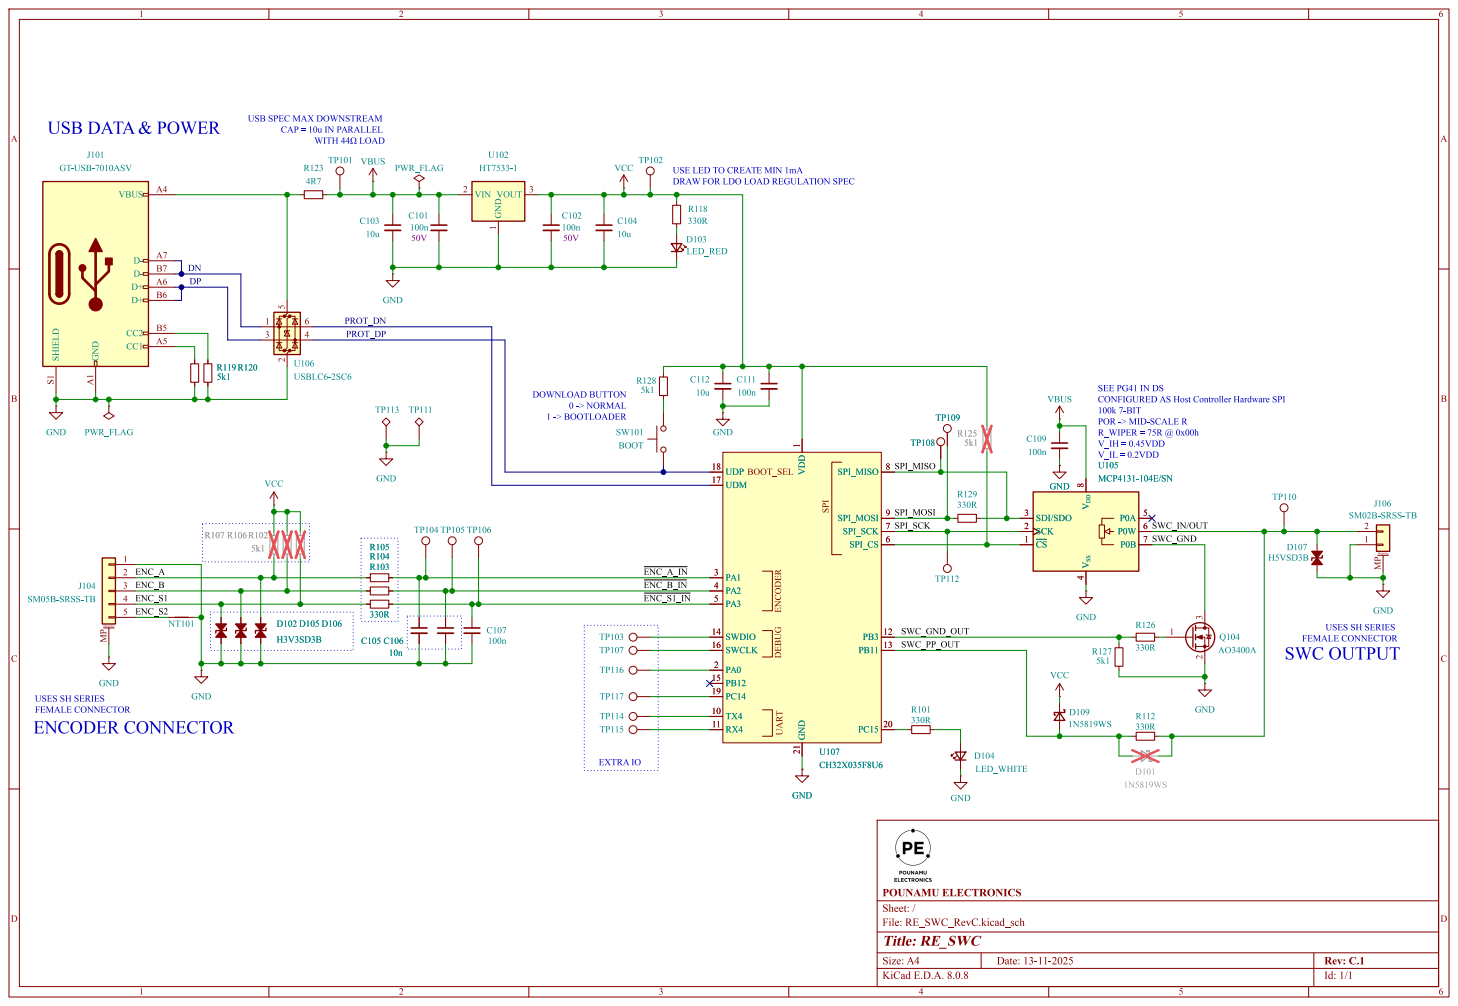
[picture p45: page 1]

CAP= 10uIN PARALLEL WITH þÿ44© LOAD USB DATA& POWER

USELED TO CREATEMIN 1mA DRAW FORLDO LOAD REGULATIONSPEC

SEEPG41IN DS CONFIGUREDAS HostControllerHardwareSPI 100k7-BIT POR-> MID-SCALE R

1 TX4 10 RX4 11 PB3 12 PB11 13 SWDIO 14 PB12 15 SWCLK 16 UDM 17 UDP 18 PC14 19 PA0 2 PC15 20 GND 21 PA1 3 PA2 4 PA3 5 SPI_CS 6 SPI_SCK 7 SPI_MISO 8 SPI_MOSI 9 U107 CH32X035F8U6 C105

1 TX4 10 RX4 11 PB3 12 PB11 13 SWDIO 14 PB12 15 SWCLK 16 UDM 17 UDP 18 PC14 19 PA0 2 PC15 20 GND 21 PA1 3 PA2 4 PA3 5 SPI_CS 6 SPI_SCK 7 SPI_MISO 8 SPI_MOSI 9 GND

File: RE_SWC_RevC.kicad_sch Sheet:/ POUNAMU ELECTRONICS

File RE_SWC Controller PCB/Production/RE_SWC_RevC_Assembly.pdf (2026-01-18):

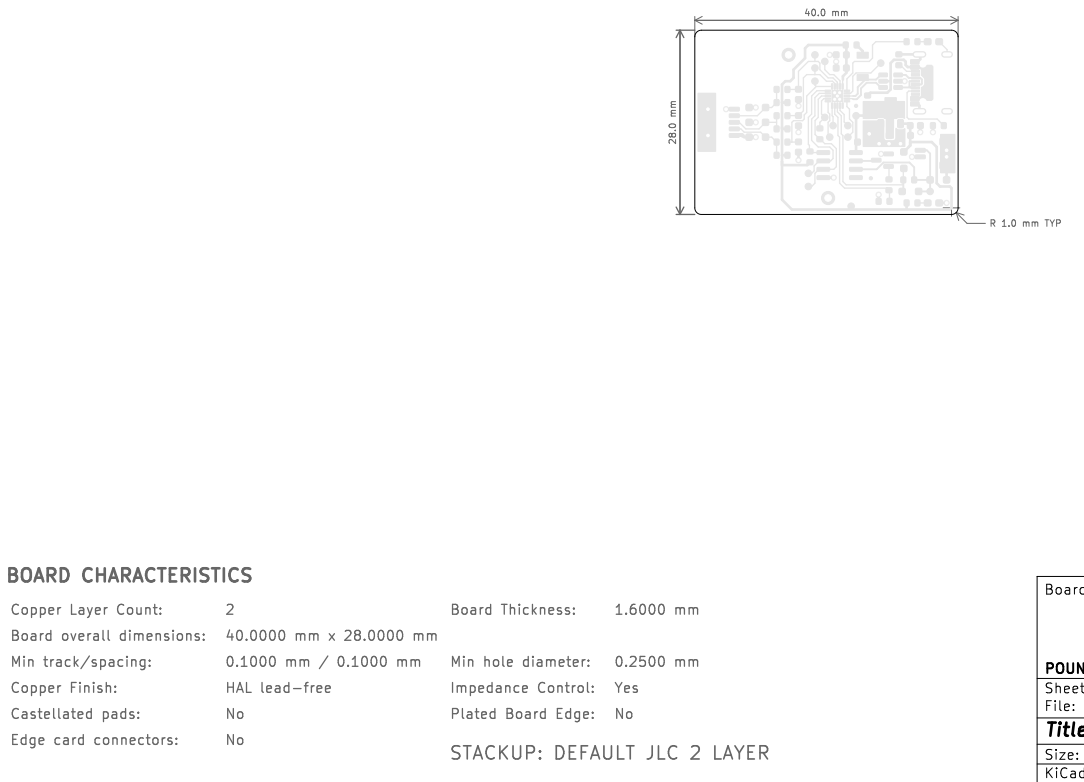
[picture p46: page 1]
D Date: 27-11-2025 KiCad; E.D.A. 8.0.8 Size: A4; Rev: C.1; Id: 1/1 Title: RE_SWC; File: RE_SWC_RevC.kicad_pcb Sheet: BoardInfo POUNAMU; ELECTRONICS; Board2Pdf:; BoardInfo; Page; 1/9 HAL lead-free; Min track/spacing: Castellated; pads:; No Copper; Layer Count: BOARD CHARACTERISTICS; Finish:; Impedance; Control: STACKUP: DEFAULT JLC 2; LAYER; No Edge card; connectors:; Min; hole diameter:; Yes 0.1000 mm / 0.1000 mm; Plated; Board; Edge:; overall; dimensions:; Thickness:; R 1.0 mm TYP

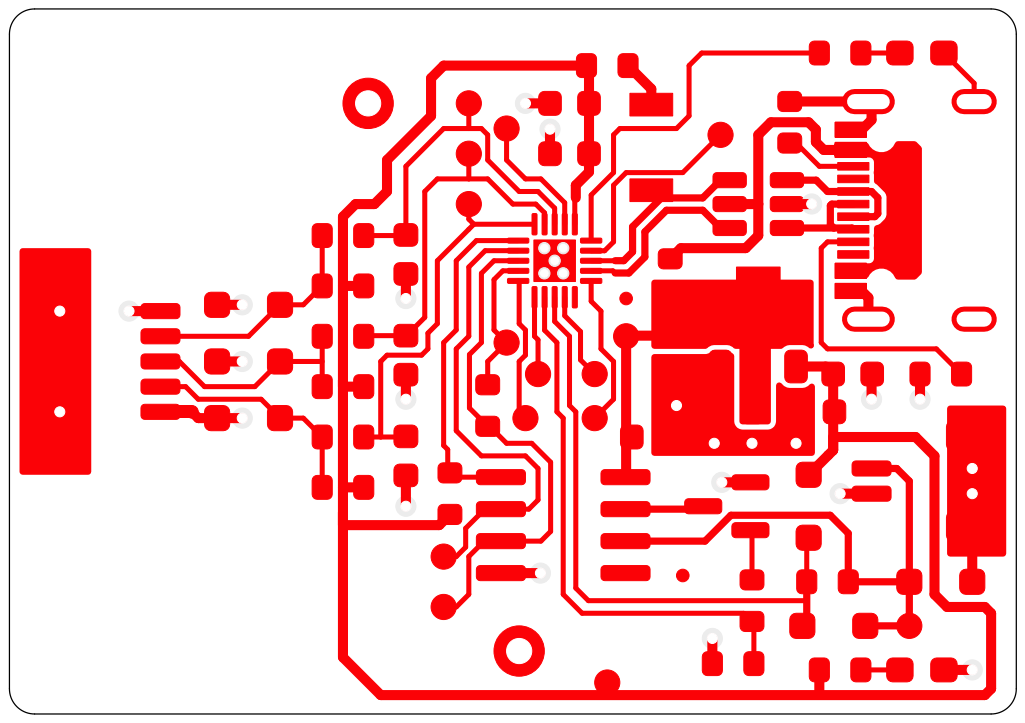
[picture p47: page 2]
6 ABCD; ABCD Date: 27-11-2025 KiCad; E.D.A. 8.0.8 Size: A4; Rev: C.1; POUNAMU; ELECTRONICS; Board2Pdf:; FrontCU -; Page 2/9

File: RE_SWC_RevC.kicad_pcb Sheet: FrontCU
Id: 1/1 Title: RE_SWC

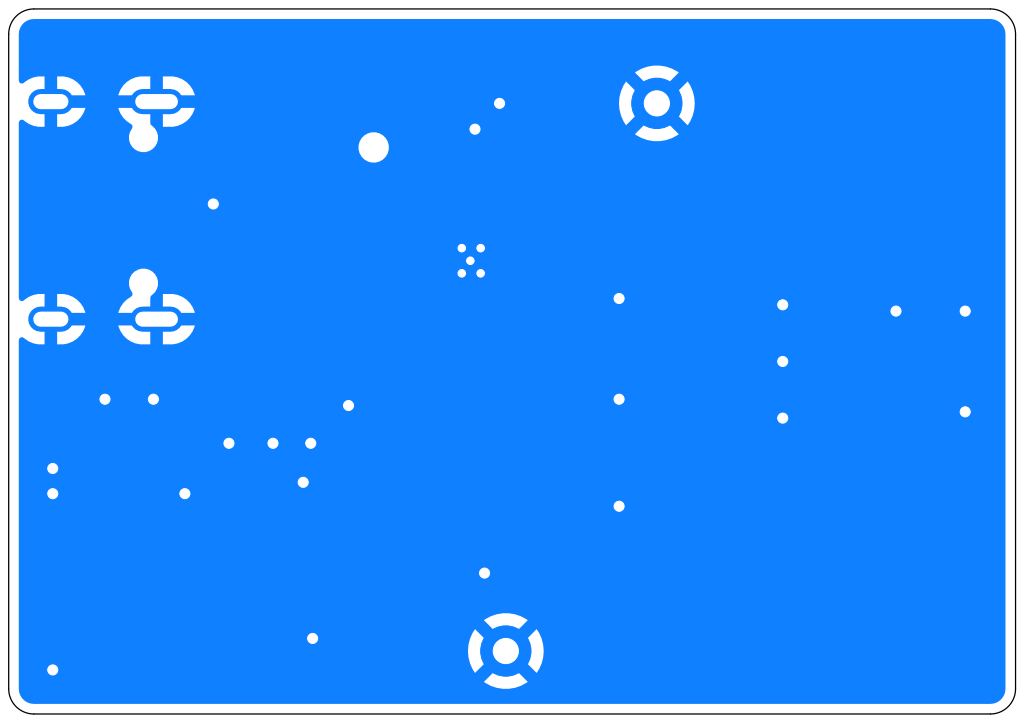
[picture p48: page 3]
6 ABCD; ABCD Date: 27-11-2025 KiCad; E.D.A. 8.0.8 Size: A4; Rev: C.1; POUNAMU; ELECTRONICS; Board2Pdf:; BackCU -; Page 3/9

File: RE_SWC_RevC.kicad_pcb Sheet: BackCU
Id: 1/1 Title: RE_SWC

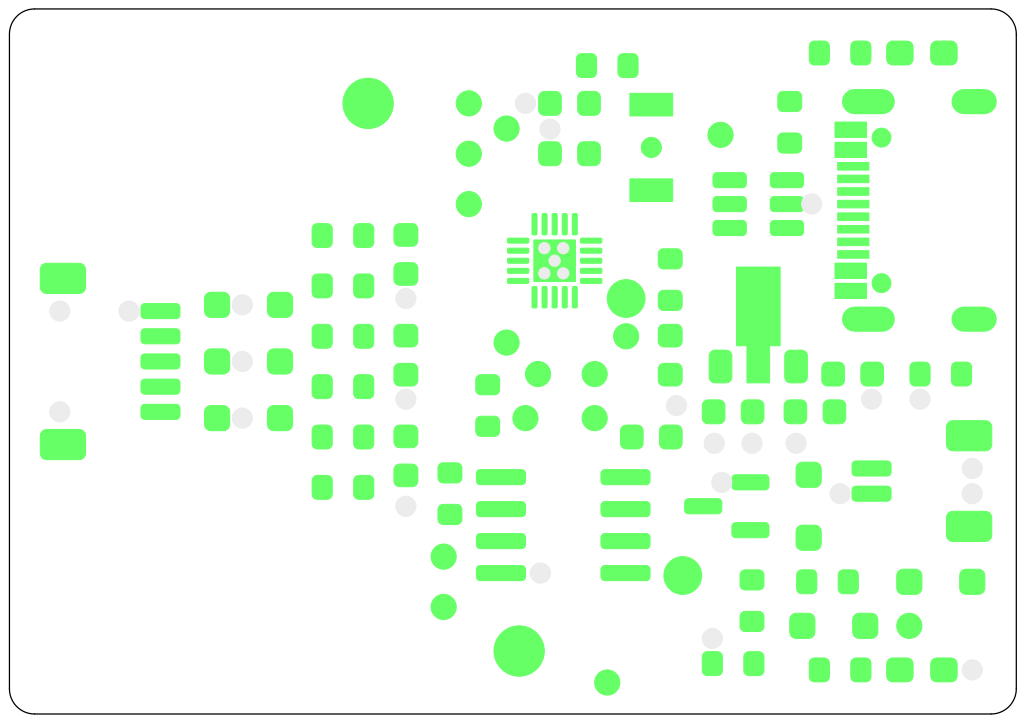
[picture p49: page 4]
6 ABCD; ABCD Date: 27-11-2025 KiCad; E.D.A. 8.0.8 Size: A4; Rev: C.1; Id: 1/1 Title: RE_SWC; File: RE_SWC_RevC.kicad_pcb Sheet: FrontMask POUNAMU; ELECTRONICS; Board2Pdf:; FrontMask; Page 4/9

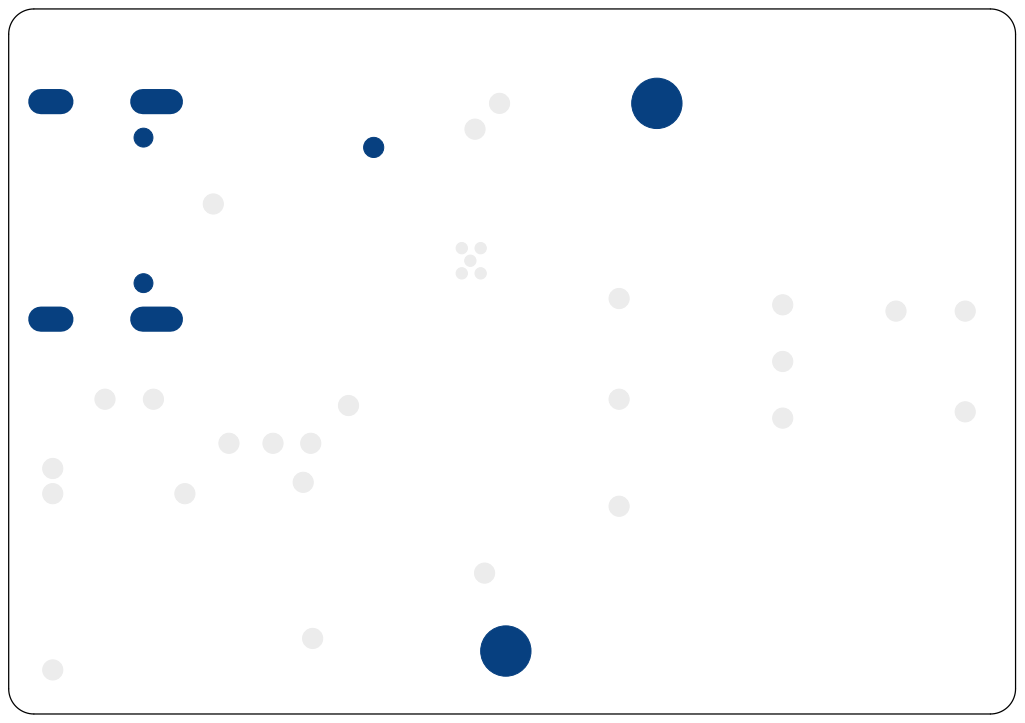
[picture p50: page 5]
6 ABCD; ABCD Date: 27-11-2025 KiCad; E.D.A. 8.0.8 Size: A4; Rev: C.1; Id: 1/1 Title: RE_SWC; File: RE_SWC_RevC.kicad_pcb Sheet: BackMask POUNAMU; ELECTRONICS; Board2Pdf:; BackMask; Page 5/9

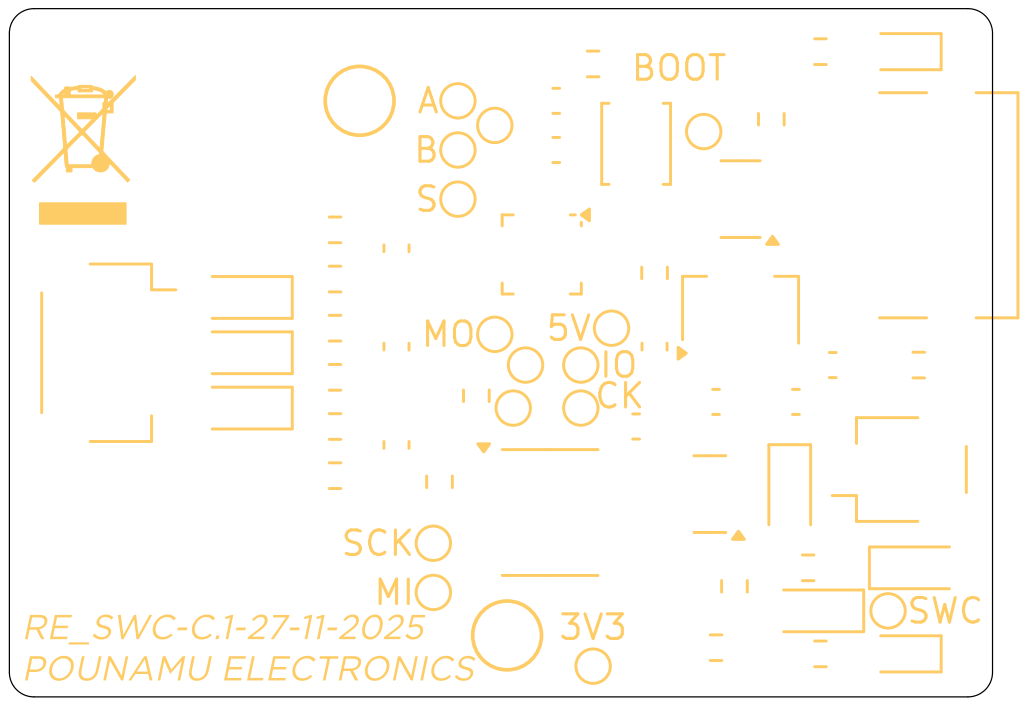
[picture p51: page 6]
6 ABCD; ABCD Date: 27-11-2025 KiCad; E.D.A. 8.0.8 Size: A4; Rev: C.1; POUNAMU; ELECTRONICS; Board2Pdf:; FrontSS -; Page 6/9 B; SWC; BOOT; SCK; MISA

File: RE_SWC_RevC.kicad_pcb Sheet: FrontSS
Id: 1/1 Title: RE_SWC

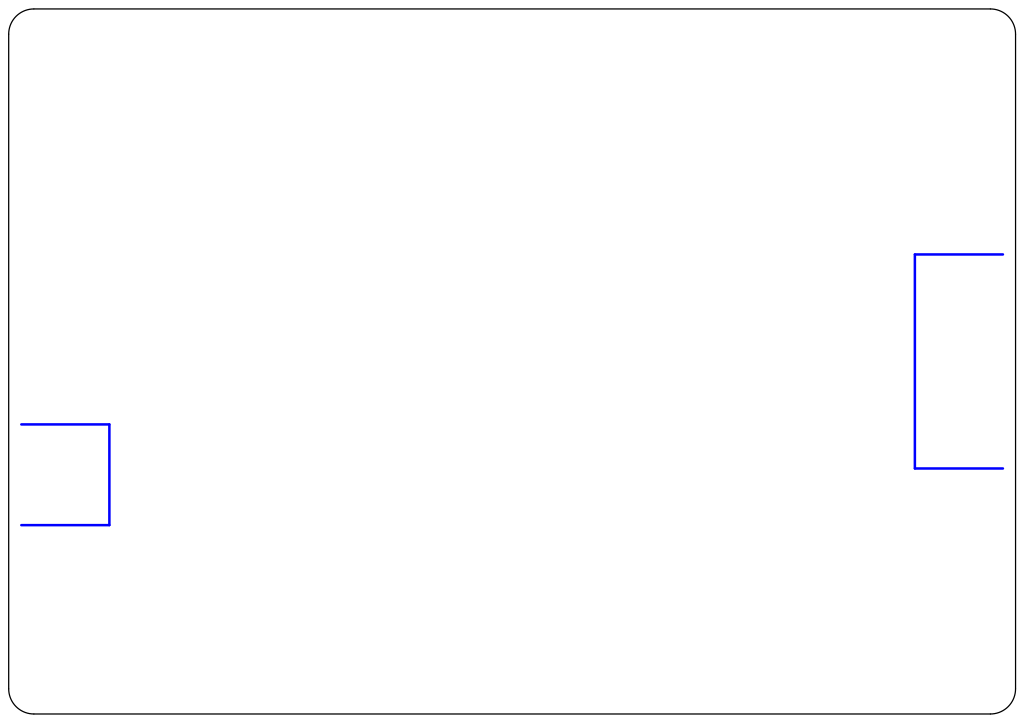
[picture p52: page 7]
6 ABCD; ABCD Date: 27-11-2025 KiCad; E.D.A. 8.0.8 Size: A4; Rev: C.1; POUNAMU; ELECTRONICS; Board2Pdf:; BackSS -; Page 7/9

File: RE_SWC_RevC.kicad_pcb Sheet: BackSS
Id: 1/1 Title: RE_SWC

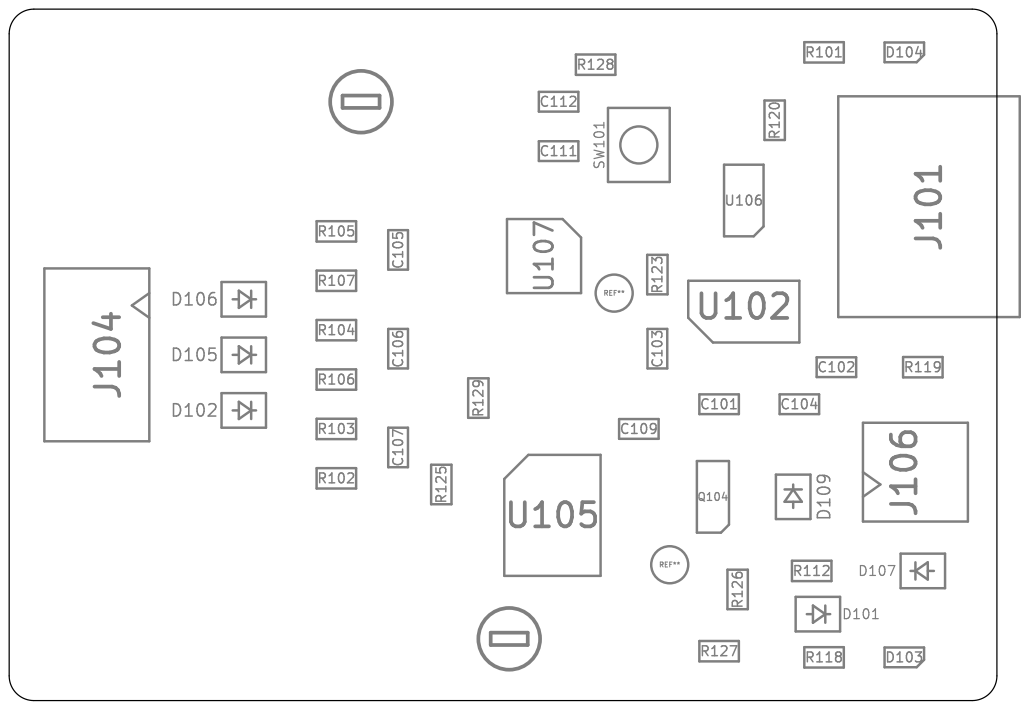
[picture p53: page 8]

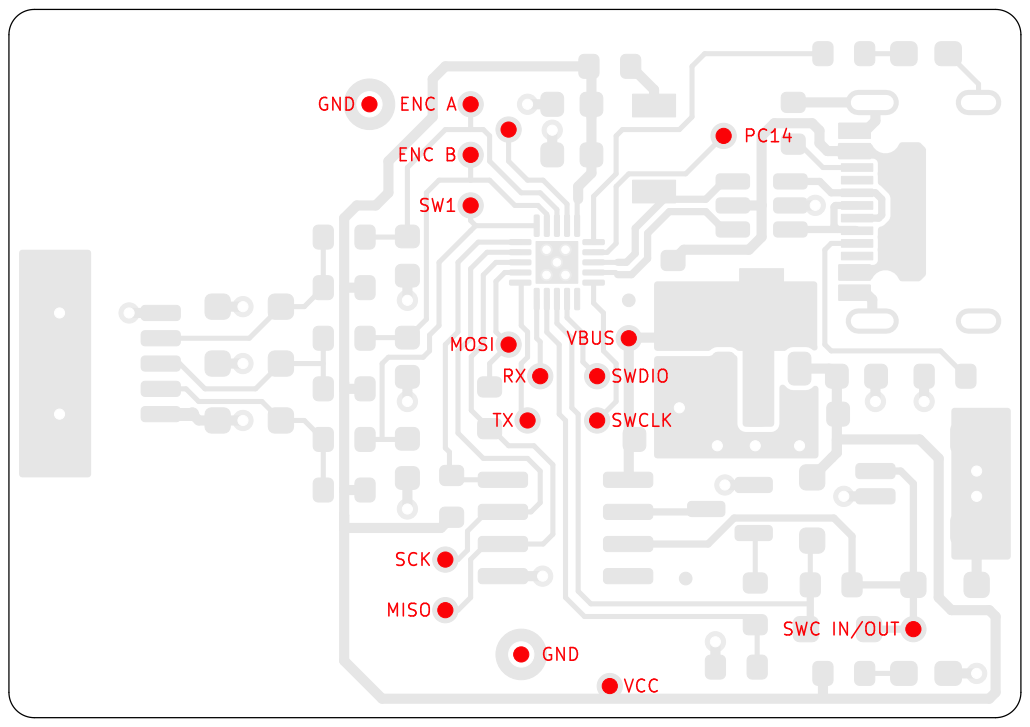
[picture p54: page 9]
D Date: 27-11-2025 KiCad; E.D.A. 8.0.8 Size: A4; Rev: C.1; POUNAMU; ELECTRONICS; Board2Pdf:; FrontTP; Page 9/9; GND; TXRX; SCK; SWCLK; ENC

PC14 VCC MISO
SWDIO MOSI SW1 ENC B

SWC IN/OUT VBUS

File: RE_SWC_RevC.kicad_pcb Sheet: FrontTP
Id: 1/1 Title: RE_SWC

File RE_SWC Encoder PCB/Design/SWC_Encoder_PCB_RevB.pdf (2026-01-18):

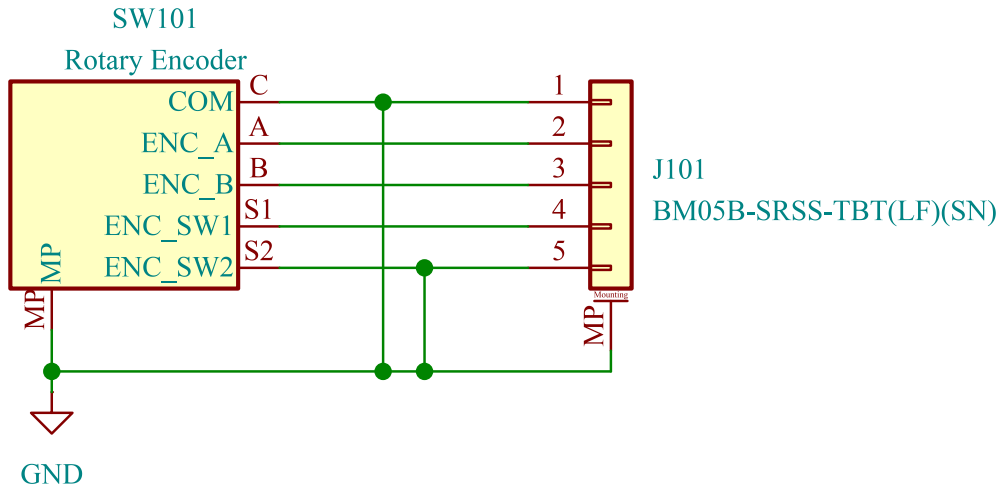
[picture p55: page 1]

J101 BM05B-SRSS-TBT(LF)(SN) GND

Id: 1/1 Title: SWC - EncoderPCB

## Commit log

2026-01-18 Update: Branch updated with HW V2 design and production files
    [BOM-RE_SWC_RevB.csv, BOM-RE_SWC_RevC.csv, BOM-SWC_Encoder_PCB.csv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]
2026-01-19 Included improved scope captures of 3V3 rail
2026-01-23 Update step models to most recent
    [CaseBase.step, CaseLid.step]
2026-10-12 Added resistance mapping table for anyone who wants to change default behaviour of Pioneer/Sony using gen res mode
2026-10-12 Updated mapping info to include tolerance of input resistance on headunit
